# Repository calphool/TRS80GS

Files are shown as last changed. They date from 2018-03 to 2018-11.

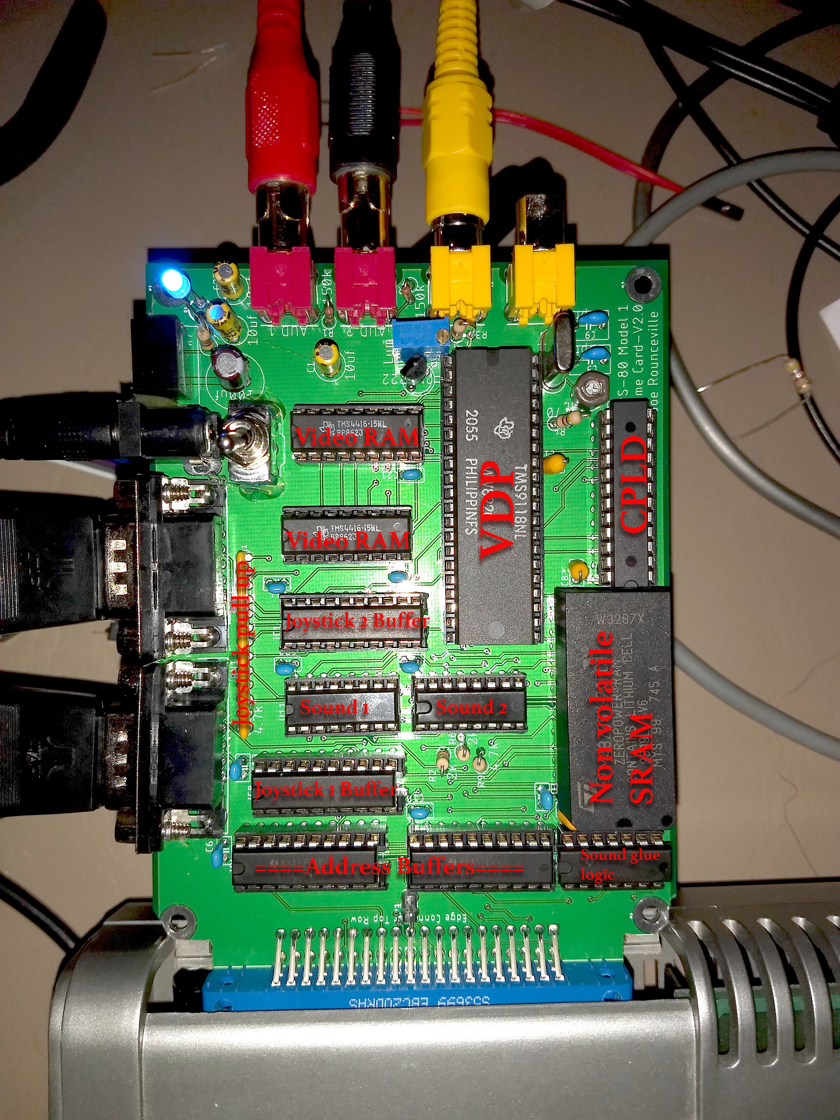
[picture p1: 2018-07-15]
img/TRS80GS_Version_3.jpg

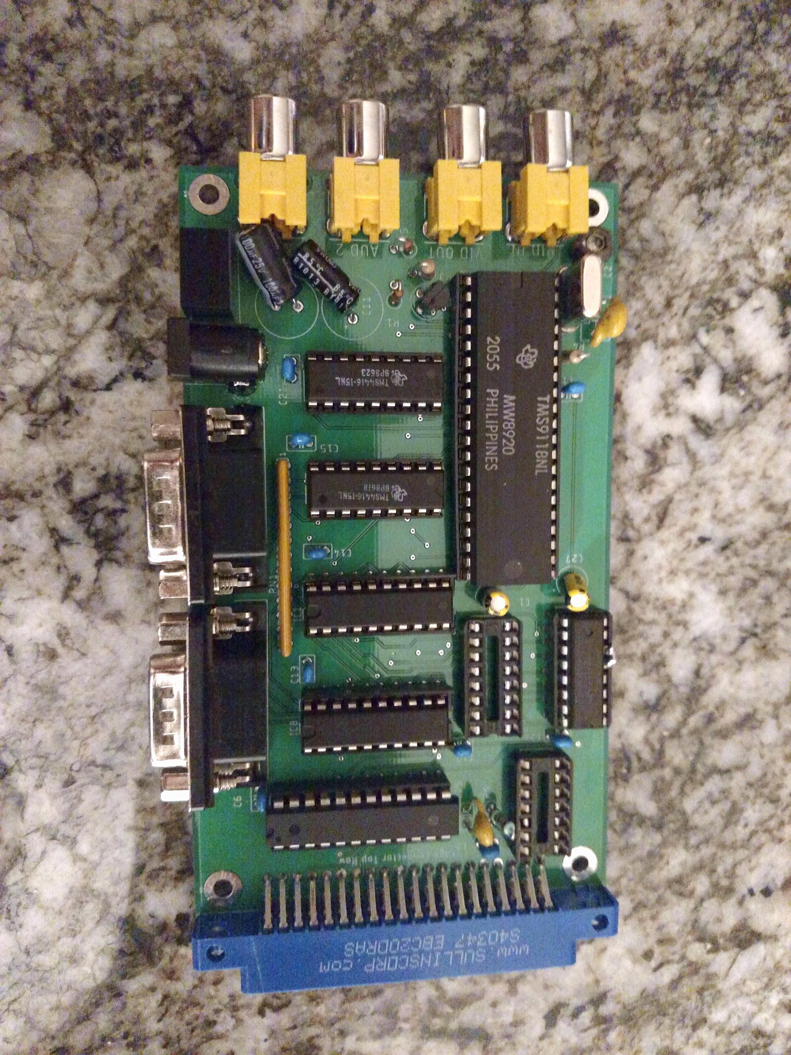
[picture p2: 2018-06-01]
img/TRS-80 Model 1 GraphicsSoundJoystick Card Prototype - Imgur.jpg

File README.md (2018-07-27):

# TRS80GS
Storage area for my TRS-80 Model 1 Graphics, Sound, Gaming, and Communication cartidge

Version 3 of PCB Version 4 of PCB

My friend's first computer was a 1977 TRS-80 Model 1.  I'm a few years younger than him, so my first computer was a TI-99/4A, 
followed soon after by an Atari 8-bit (800XL I believe).

For some reason my friend kept trying to assert that his *Trash-80* was in some way superior to all home computers of the era, 
and of course this couldn't stand.  I decided to see what all his fussing was about.  I learned some Z80 assembler, 
started hacking a TRS-80 emulator, and eventually got somewhat comfortable with Z80 assembler (I still prefer 6502 assembler).  I 
tried to do some graphics stuff, but *man*, TRS-80 Model 1's *barely* have the ability to do anything you'd call "graphics." 
I did a couple of snow-field type demos, but it looks more like slowly falling bricks on some low-gravity planet than snow.

The TRS-80 uses these goofy ["pseudographics" characters (2 by 3 grids)](https://www.classic-computers.org.nz/system-80/manuals_tm3_page33.jpg), 
and you have to do everything by selecting the right "character" in order to plot these huge blocky pixels.  Your resolution is effectively 128 x 48, and 
it's a pain to work with, because you're actually manipulating a 64 x 16 text grid.  I wrote some assembler code so that I could at least *address* 
the TRS-80 Model 1 screen *as if* it had 128 x 48 resolution, which I've included in this repo (see the snow.asm code, it's the FSETGR routine).

Eventually the day came that I thought "Ok, I'm going to try to write a game for this nasty old thing."  I *really* wanted 
graphics, sound, and a joystick, but alas that wasn't really in the cards for an unmodified TRS-80 Model 1.  So I began 
imagining what it would be like to augment a TRS-80 Model 1 so that it was *at least* as capable as *my* first computer, the 
TI.  I found a couple of dodgy designs for such devices from the era, but they were hand drawn, hard to read, and loaded with 
components that are no longer available.  So, I decided to design my own.

This repo is a gathering place for my work so far.  I've designed a cartridge that will plug into the TRS-80 Model 1 expansion 
port.  It is built around a TMS9118A video display processor (a close relative of the one used in the TI-99/4A and Colecovision).
It also includes two SN76489 sound chips (also from TI-99/4A, but *better* because we have two of them -- six voice harmony baby!)
I've also included a 74LS244 on the bus attached to an Atari 2600 joystick port (DB9), which in theory will give me the 
ability to poll for joystick condition.  That may end up being a bad design, since it's not using any interrupts, but I 
figured I'd start simple and if I need to implement interrupts I'll have to dig into how the TRS-80 deals with them.

**Be Aware**:  ~~I haven't built or tested my card yet (as of March 2018).  So it *probably* doesn't work as is.  We'll see as soon as 
I get finished testing the components individually with an Arduino as a kind of "hardware emulator".  I don't want to risk a 
"40 year old museum piece" while I figure out how to get the "glue" working properly.~~  I *have* now built a working prototype.  
You'll find the eaglecad and such in the rev2 folder (though you'd be better off using the rev4 version).  There's also some source code to test it once you get the board built.  

**Update**:  The photo is of the Rev4 version of this card.  It's fully working, and better than the rev2 and rev3.

Theory of Operation
===================

~~If you examine the *original* schematic for the board, you can see that it's got a bunch of decoding logic, and some SPDT dip switches.  The theory here 
is that I'm attaching the decoding logic to the lower half of [the expansion port's address bus](http://www.classiccmp.org/cpmarchives/trs80/mirrors/kjsl/www.kjsl.com/trs80/mod1intern.html) 
and using the OUT* and IN* pins to decide what we're doing.  In this way, the port address numbers will be adjustable.  
I'm hard wiring bit zero as a toggle bit though, so really you're adjusting the 7 most significant bits, and bit zero toggles 
between related devices or related pins on a device.~~

Strike all that... I pivoted on the design by rev2.  We got rid of silly things like glue logic chips (well, until rev4) and SPDT dip switches, and simply added 
a [CPLD](https://www.microchip.com/wwwproducts/en/ATF22V10C) that manages the address decoding and control signal generation.  The code for the CPLD is now in the repo.  So you 
"adjust" the addresses in code now, not with SPDT dip switches (what was I thinking?)  You program the CPLD with a Stager 4800 programmer, and a very particular version of 
its software (VSpeed 5.0).  Details are in the .PLD file in the repo.  I may eventually add another CPLD and get rid of the couple of glue chips I've got in the rev4 version.  Right now it doesn't 
seem worth it (get rid of two small chips and replace them with a big one?  Sounds like break even right now).

Rev3 includes some addtions.  First, it fixes the sound problem that the rev2 board had so we get both sound chips working (all 6 audio channels and 2 noise channels).  Second, it includes
a [32k SRAM](https://www.mouser.com/ProductDetail/511-M48Z35Y70PC1).  The original expansion system for the TRS-80 used DRAMs, but SRAM actually ends up being much better, especially when you use a non-volatile one like I have.  The Rev3 board 
also cleans up the joystick bodges that I had to do on the Rev2 board.  Rev3 works fully, and I've been building a Pacman game on it.

~~Rev4 is currently (July 2018) being built by our Chinese friends at allpcb.com, and it~~ is an upgraded version of Rev3 with one major improvement -- a [UART](https://en.wikipedia.org/wiki/16550_UART).  I 
~~*should* be~~ am able to connect a [FTDI cable](http://www.ftdichip.com/Products/Cables/USBTTLSerial.htm) via USB from my Mac to this UART and I should be able to transfer binary data back and forth.  
Initially I'll just use it to move my Pacman code back and forth, but in truth with a fully functional UART, I could build a kind of network interface and create something loosely equivalent to a LAN share, 
which would be sort of cool.  In fact, I *could* probably build a SLIP interface and do stuff like surf the web or use FTP from a 40 year old TRS-80 Model 1, but we'll save all that software work for a later date.

The only trouble with having a UART is that now I have *two* interrupts to deal with, so you won't be able to simultaneously use the VPD's interrupts *and* the UART's interrupts.  I've included
a jumper to allow you to switch which one you're working with.  I *suppose* I could add a latch behind an address so that you could tell which interrupt was being invoked, but honestly I 
can't imagine why we need to be both loading data *and* altering the screen at the same time, so Rev4 will use a jumper.  I think I'll start out without coding any interrupt stuff and see what I can get away with
using plain old polling.  It'll be slower, but simpler.  Once I get it working, then I'll look into trickier stuff like interrupt handling in z88dk.

Rev4 is now here and "working" though it took a little bit of hacking to get it up and running.  The original design for 
Rev4 included a separate crystal for the UART (1.8432mhz), but that proved problematic.  It caused the VDP crystal to 
act flaky due to interference.  So, I decided to try removing its crystal and all its support caps and resistors, and just 
drive the XTAL in for the UART from the CPUCLK output of the VDP.  It's the wrong speed (3.5mhz instead of 1.8432mhz), but 
luckily the UART has a divider value that you plug into a register during setup that allows it to use any chip slower than
16mhz.  I coded a couple of little test programs, one for the MAC (the "server") and one for the TRS-80 (the "client").  I
was able to transfer data back and forth, but I'm reaching out to folks on reddit to see if there's a better way to code 
it, since I have an arbitrary 8 millisecond wait on each byte transferred because I don't understand hardware flow control.

TMS9118A
--------
This little VDP chip has an interesting history.  It didn't disappear with the TI-99/4A.  It got used in the Colecovision, and
then its descendants got picked up and used in the MSX computer systems.  Later, it evolved into the graphics and sound chip
used in the Sega Master System and Sega Game Gear.  It has a bank of attached DRAM memory (16k), and you access this memory through
an 8 bit data bus and a few bus flags (MODE, CSR*, and CSW*).  It also has CAS and RAS signals to keep the DRAM running.  So, *technically*, in addition to getting decent graphics and 
sound with this card, we're also giving the TRS-80 Model 1 an additional 16k of RAM, though it's only accessible through a 
tiny keyhole of two IO ports, and much of it is used up by the VDP chip itself (depending on what mode you set it to).

~~At the time of this writing (March 2018), I've managed to bodge up a working TMS9118A on a breadboard, and drive it with an 
Arduino.  I've uploaded the Arduino code for that, and an incredibly frightening breadboard photo that looks like something out of 
the movie Aliens.  The code doesn't do anything too spectacular, but just changes the background color, which means that 
I've successfully managed to figure out how to drive the WRITE side of the chip (writing to what the VDP calls "control 
registers", which are how you set up almost everything in the VDP).  I've also included a small video showing it doing that.~~

We're way past that stage now.  The TMS9118 works like a dream, and I've been building a Pacman clone against it, using the z88dk C compiler.  So far I'm fitting inside my nice 32k RAM addition
just fine.  There's a lot of fluff in my code, and I'm pretty sure I could get it crammed down at least 25% if I worked at it.  Right now I've got an animated pacman that can move around inside
the maze, and I've got the intro music working.  Ghosts and dots coming soon....

SN76489
-------
~~I haven't done much with the sound chips yet, but hopefully they'll be a bit easier to manage than the VDP.  Bit 0 of the 
address bus will toggle between them.  Stereo baby!~~

Sound didn't work quite right in the rev2 board design.  There's a "Ready" line on the SN76489 that needed to be tied to the WAIT line on the TRS-80 interface.  Why?  Because the SN76489 doesn't
like receiving a second byte when it's still processing the first one.  I *could* write all my code to put a delay inbetween each byte send, but that's kind of lame and non-deterministic.  The
WAIT line was originally conceived so that the TRS-80 could interface to "slow" peripherals, and although the sound chip isn't *super* slow, it seemed the way to go was to tie that READY line 
to it.  Unfortunately on the rev2 board that meant that I couldn't use *both* sound chips, because I didn't have a free OR gate anywhere to run the two Ready lines through.  So, I pulled one of them
and just wired the other one up on the rev2 board.  It worked as expected.  This has all been cleaned up in the rev3 and rev4 boards.

74LS244
-------
This is managing the joystick switches.  It takes 5 switches to handle up, down, left, right, and trigger.  ~~I don't have any
kind of debounce circuit in there, so I'm guessing that'll be a problem.  We'll see when we get there.~~

Joystick circuits worked more or less flawlessly, though I had stuff wired backward on the PCB for rev2.  I had to bodge some jumper wires to get them working because of that, but that's all cleaned 
up in Rev3 and Rev4.  I originally was toying with the idea of building some kind of one-way parallel interface that used the joystick ports, but the more I thought about it the less I liked it and
decided to add the UART instead.

ExtVid
------
I don't really know if I'll do this, but it's sort of an intriguing idea.  Apparently the TMS9118A has a "video input" pin, 
believe it or not.  In principle at least, I could feed the video out of the TRS-80 to the video-input of the TMS9118A, and it
will *combine* the video together, with the TRS-80's video feed at the bottom of the stack of planes that the TMS9118A creates (which, 
by the way is how it manages sprites -- 32 of them as separate planes stacked on top of each other).  If I do this, and it 
works, it could create some interesting possibilities.  You'd still have the "feel" of a TRS-80 Model 1 with its nasty, clunky
pseudographics, but then you could overlay color and sprites over the top of it.  I guess we'll see when we get there.  The 
current (March 2018) schematics don't implement this idea.

(July 2018) I haven't done anything with ExtVid yet.  I've come to realize that it's unlikely to just work out of the box, because the 
RESET line on the TMS9118A does double duty as some kind of video sync signal.  So I'd probably have to come up with a sync separator 
circuit for the ExtVid line, then amplify that signal up to whatever ungodly voltage causes the RESET to act like a SYNC signal.  I probably should just
hook up a video signal to see how bad it tears as it moves down the screen -- maybe it's still usable without all that extra circuitry -- just haven't 
tried it yet.

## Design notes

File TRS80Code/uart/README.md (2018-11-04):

Getting UART code working for TRS80GS
-------------------------------------

Make sure you've followed this power-up sequence:

    A) Turn on TRS80GS card
    B) Power on TRS-80
    C) Plug in FTDI cable to Mac USB
    D) Start uart_server executable

Also, don't use the Reset button on the TRS-80.  It creates chaos.  Use the power button.

The UART file upload/download system works in two parts.  First there is a TRS-80 binary module
that loads into the SRAM of the TRS80GS card.  Steps 1 - 6 must be completed any time you 
change the uart.c module.

The second part is the Mac server component.  It runs on your Mac (although it *might* work on a)
PC that has GCC, I've not tried it there, and I wouldn't be surprised if the serial code didn't 
work the same way).  It basically listens for commands from the UART chip and responds appropriately.

Step 1.  Compile uart.c using cmp.sh, which produces a .cmd and a .wav file 

	:~/z88dk/cmp.sh uart 55000

	Note: the 55000 is the address you want the uart client code to load to.  Make sure that the 
	.cmd file fits inside the space you specify.  The address space for the Z80 is 
	0x0000 to 0xffff.  If your .cmd file is 7k, then you would use 0xffff-(7*1024), or
	58368 (0xE400).  You can use a lower value that that (and probably should), but that would be 
	the maximum.  Depending on the details of how the compiler optimizes, that may not be low 
	enough.  I generally subtract an addtional 3000 so that I don't have to worry about it.

Step 2.  Load the uart.wav file into Audacity and amplify it 8 db.  (You must allow clipping.)

Step 3.  Turn on your TRS-80 Model 1.  When you see the MEM SIZE? prompt, type 18000
         Then connect your TRS80 cassette line to your Mac or PC.

Step 4.  On the TRS-80 type:

         SYSTEM

         *? A

Step 5.  Press PLAY on Audacity

     Note: if you are using an official TRS-80 cassette cable, you'll be using the black 
     plug into your Mac or PC.  Also, note that as the data loads, you should see a couple of 
     asterisks in the top right side of the screen, with the right one flashing off and on
     as the data loads.

Step 6.  Once the data is loaded type:

         *? /55000

     Note that the number you type should match what you specified in step 1.  The UART 
     program should appear on screen and ask you for a command.  You can type ? to see 
     the list of commands it supports.

Step 7.  Compile the Mac server component.
     :~/TRS80GS/OSXCode$ gcc uart_server.c

Step 8.  Execute the Mac server code.
     :~/TRS80GS/OSXCode$ ./uart_server

     Note: you should see something like:

         Starting...
         Getting devices...
         Searching for non-bluetooth tty devices...
             ...ignoring bluetooth device: tty.Bluetooth-Incoming-Port ...

         Found 1 valid serial device(s).
         Defaulting to serial device: tty.usbserial-AI055XFC
         Opening...
         Waiting for command.

Step 9.  On the TRS-80 command prompt, type:

         >LS

     Note: you should see a list of files that are in the same directory as the uart_server. 
     If you have no .CMD files, you need to find some and put them in that directory and try again.

Step 10.  To load a .CMD file, at the TRS-80 type:

         >GET LASERDEF.CMD

     Note:  You will see a progress bar as the .CMD file is loaded into memory and the console on
            the Mac uart_server app will show a percentage loaded, like this:

		     Get Command requested...
		        GET LASERDEF.CMD
		        Reading Object block, addr 0x8000, length = 128 (0 percent complete)
				Reading Object block, addr 0x8080, length = 128 (1 percent complete)
				Reading Object block, addr 0x8100, length = 128 (2 percent complete)
				Reading Object block, addr 0x8180, length = 128 (3 percent complete)
				Reading Object block, addr 0x8200, length = 128 (5 percent complete)
				Reading Object block, addr 0x8280, length = 128 (6 percent complete)
				Reading Object block, addr 0x8300, length = 128 (7 percent complete)
				Reading Object block, addr 0x8380, length = 128 (9 percent complete)
				Reading Object block, addr 0x8400, length = 128 (10 percent complete)
				Reading Object block, addr 0x8480, length = 128 (11 percent complete)
				Reading Object block, addr 0x8500, length = 128 (13 percent complete)
				Reading Object block, addr 0x8580, length = 128 (14 percent complete)

    After it finishes loading, you should see:

        PROGRAM ENTRY POINT: xxxxxx
        ENTER 'G' TO RUN AT ENTRY POINT, or 'C' TO CANCEL

    Normally you want to type G at this point.  If you know what you're doing, you could type C to 
    get back to the command prompt to load something else into memory.

Step 11.  Once you're done with whatever you loaded, you can restart your TRS-80 and the code for the 
          uart client should still be memory resident (as long as whatever you loaded didn't corrupt it).

          So, just start your TRS-80 again, use 18000 for your memory size, type SYSTEM and then:

          *? /55000

          to launch the UART client to load something different.  If the UART client gets corrupted, 
          you will need to run steps 4 - 6 again.  However, it is rare for a .CMD to use memory outside 
          of where it was loaded, so this should rarely happen.

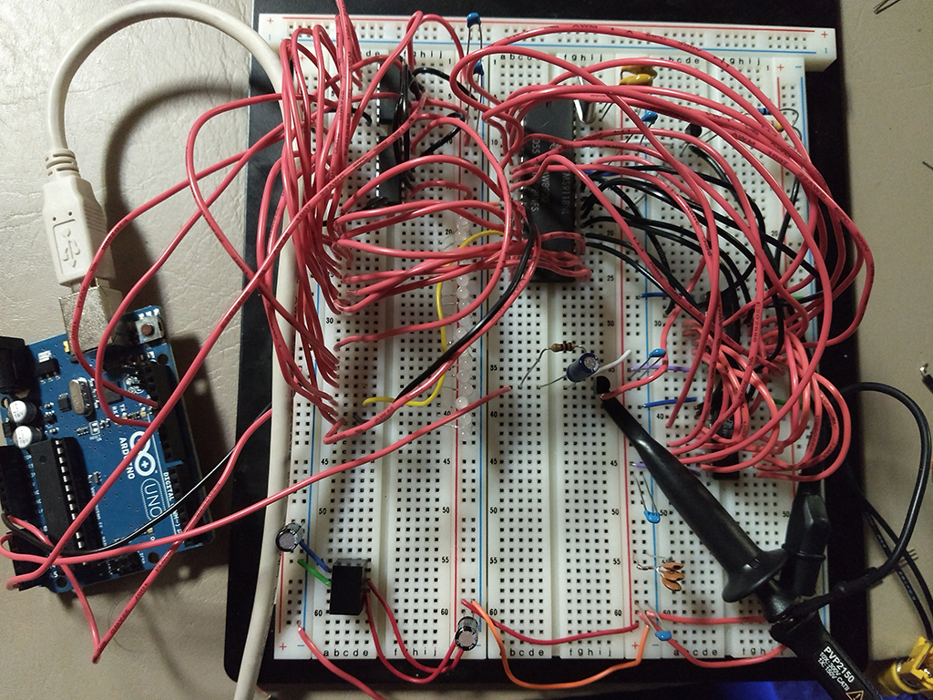
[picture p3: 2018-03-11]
arduino_prototyping/Breadboard_Monstrosity.jpg

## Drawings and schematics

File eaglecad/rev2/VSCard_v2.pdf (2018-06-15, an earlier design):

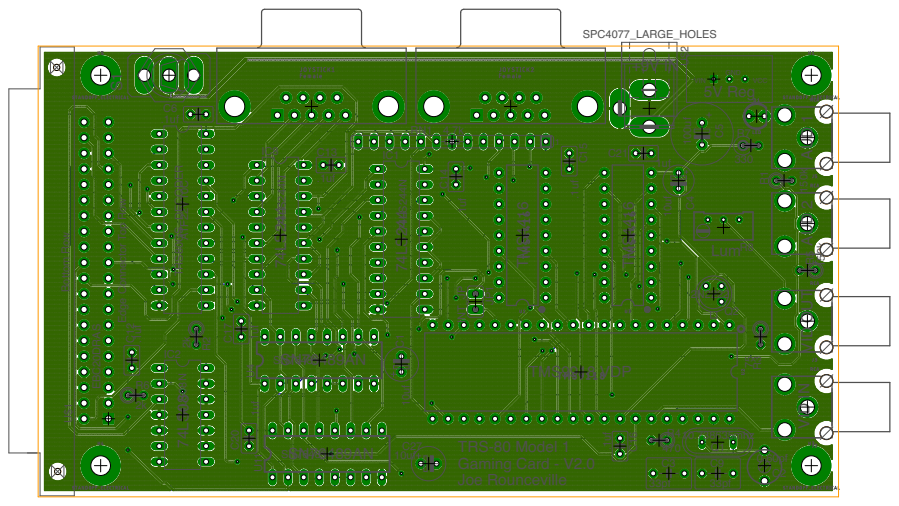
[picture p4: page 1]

Edge Connector Top Row

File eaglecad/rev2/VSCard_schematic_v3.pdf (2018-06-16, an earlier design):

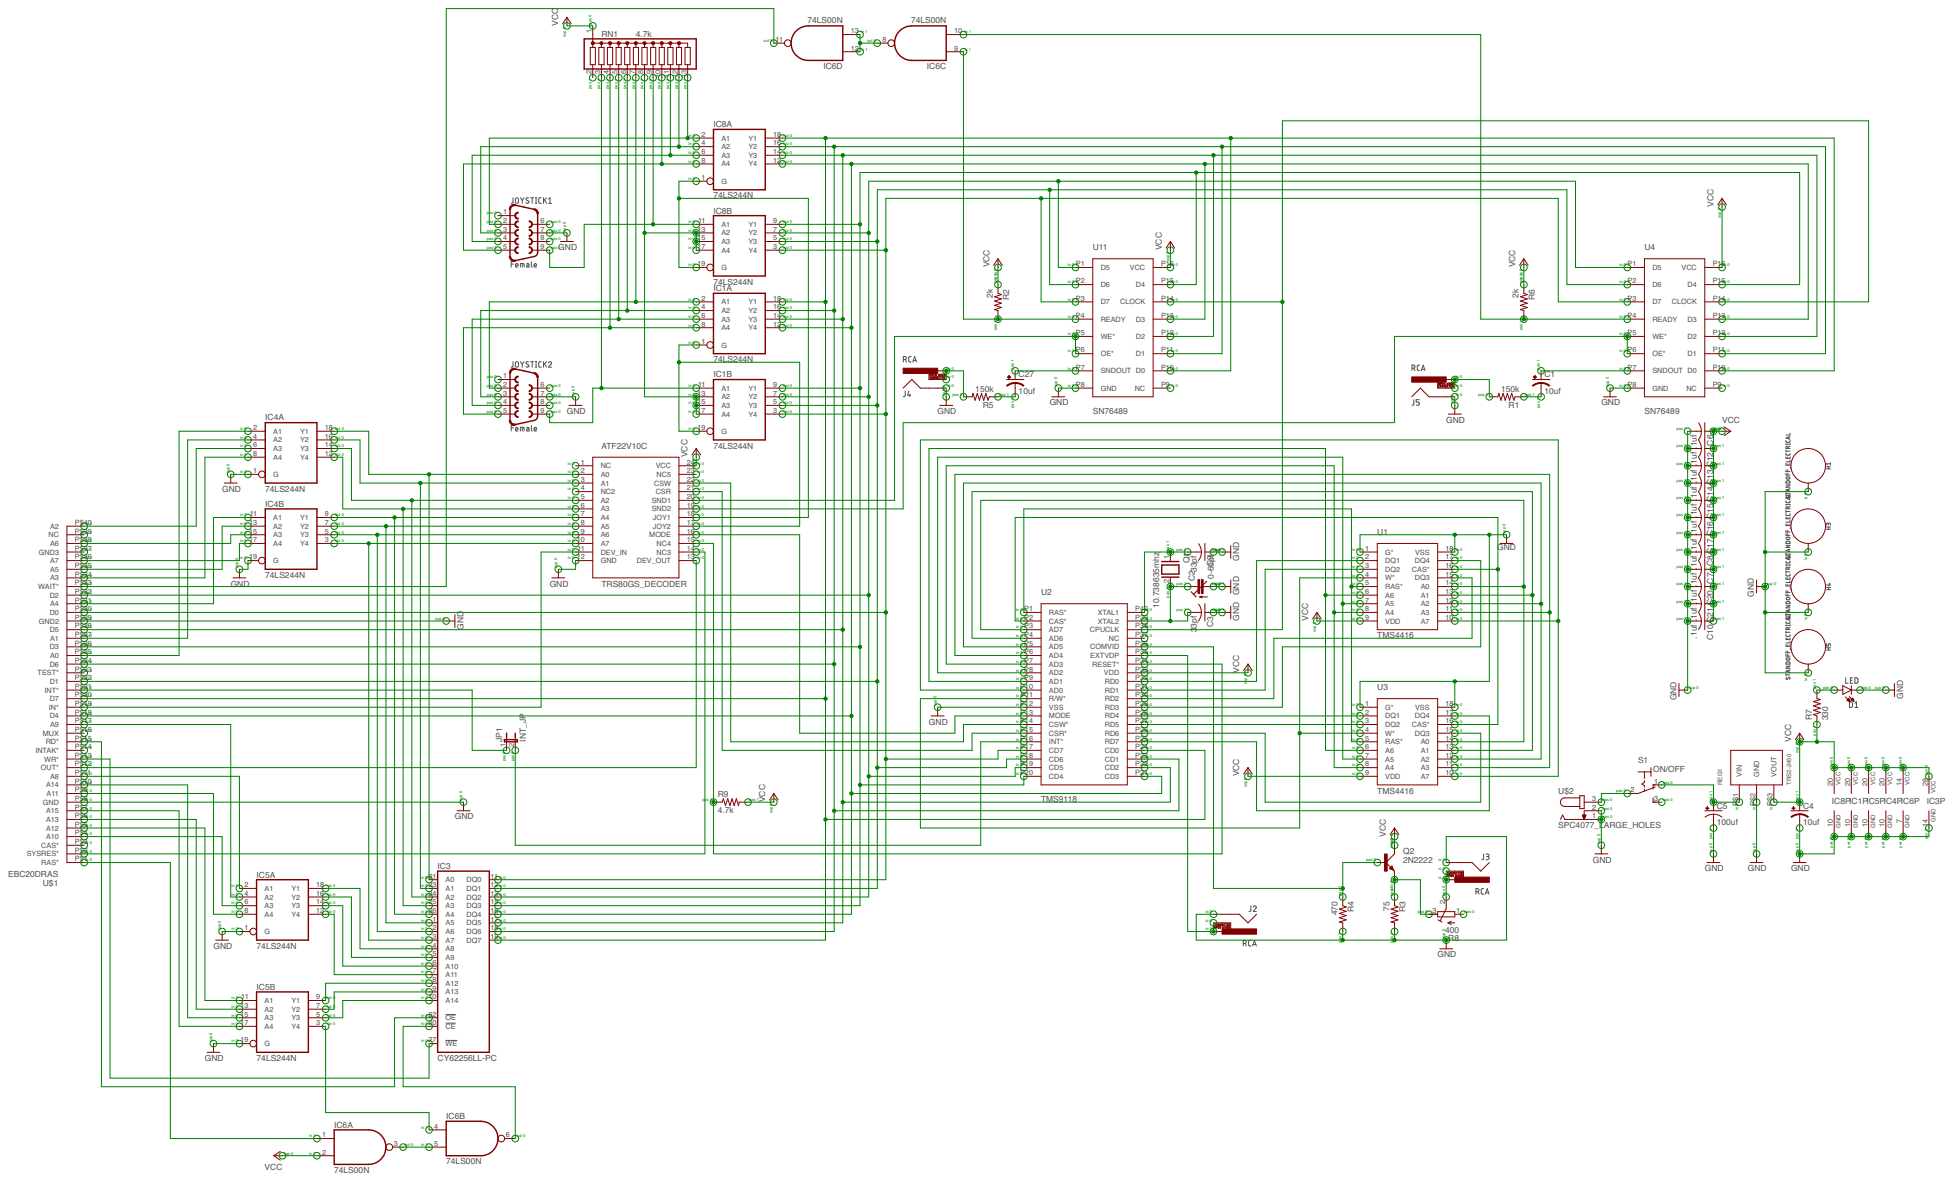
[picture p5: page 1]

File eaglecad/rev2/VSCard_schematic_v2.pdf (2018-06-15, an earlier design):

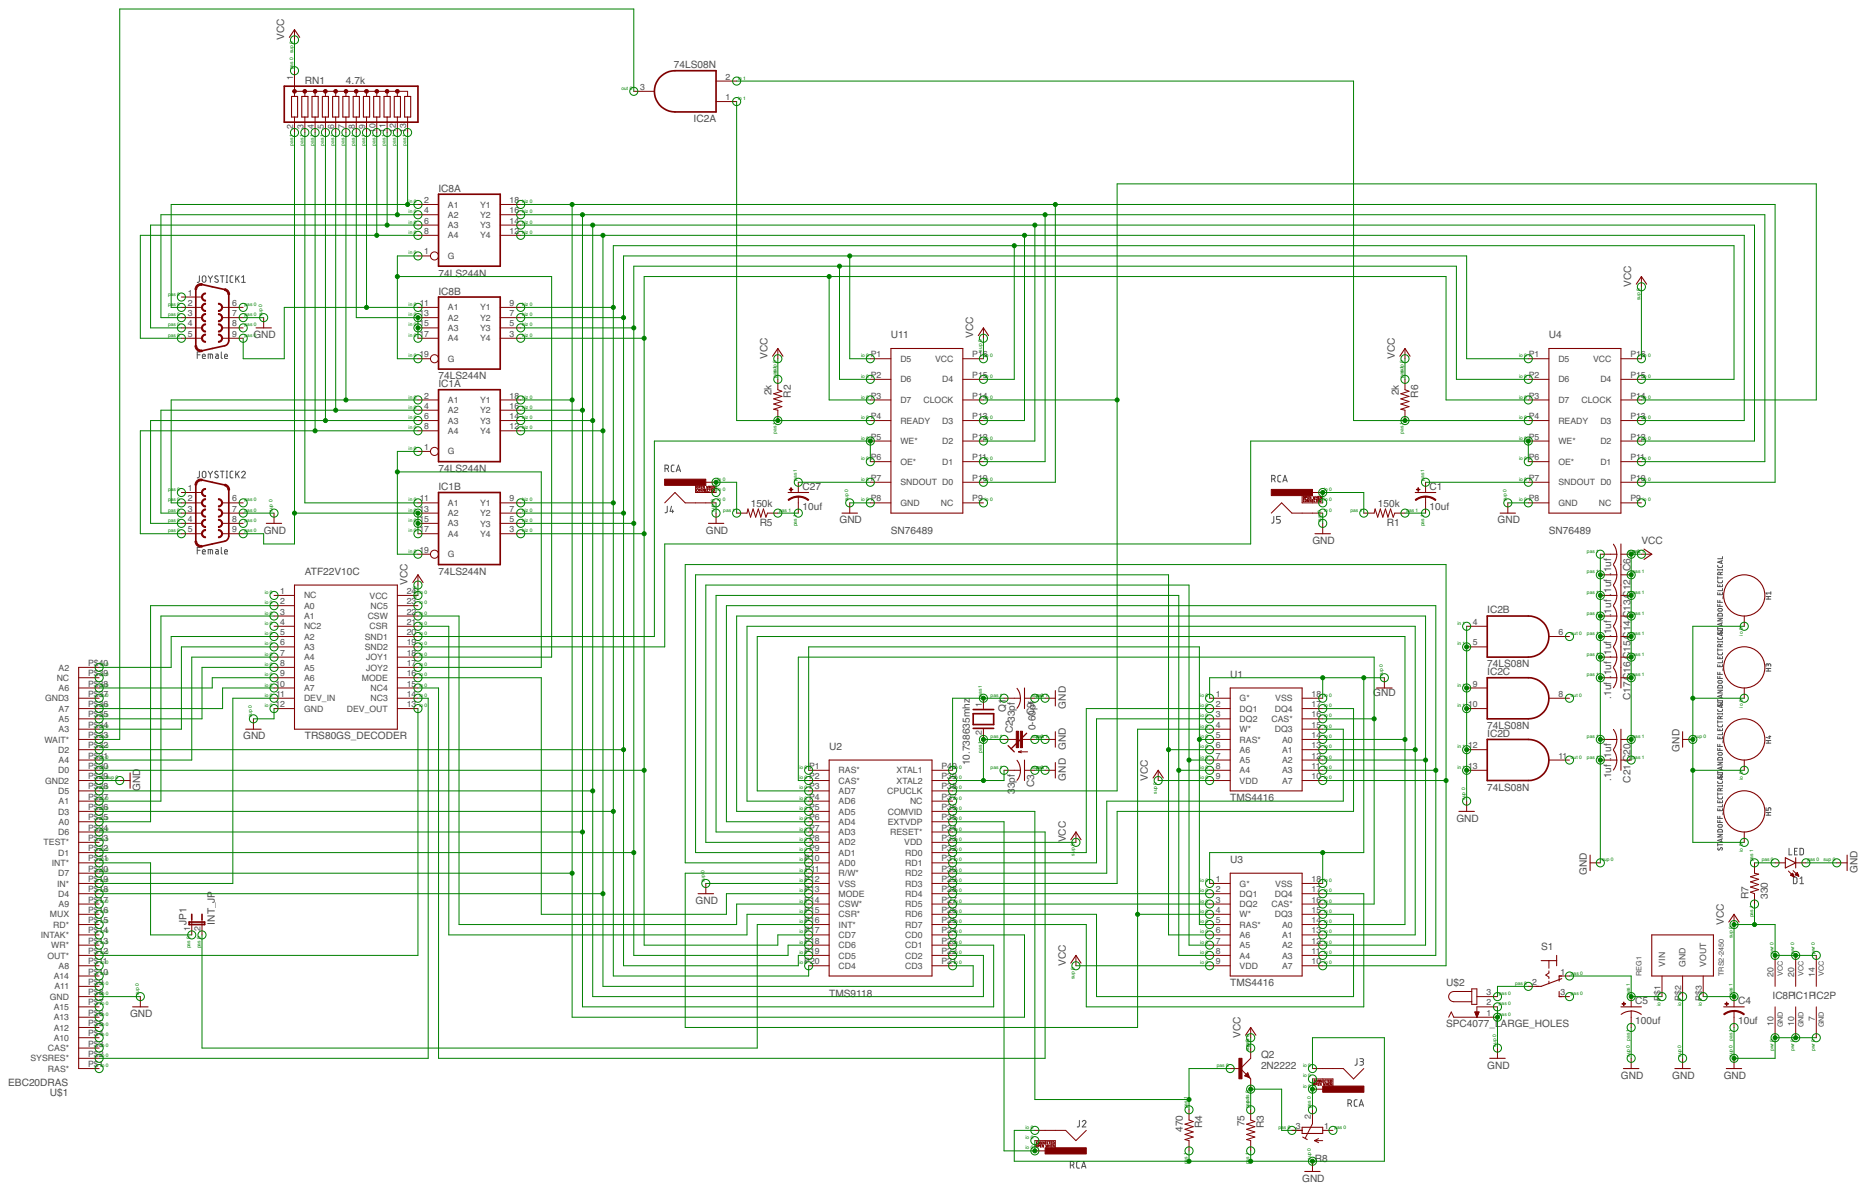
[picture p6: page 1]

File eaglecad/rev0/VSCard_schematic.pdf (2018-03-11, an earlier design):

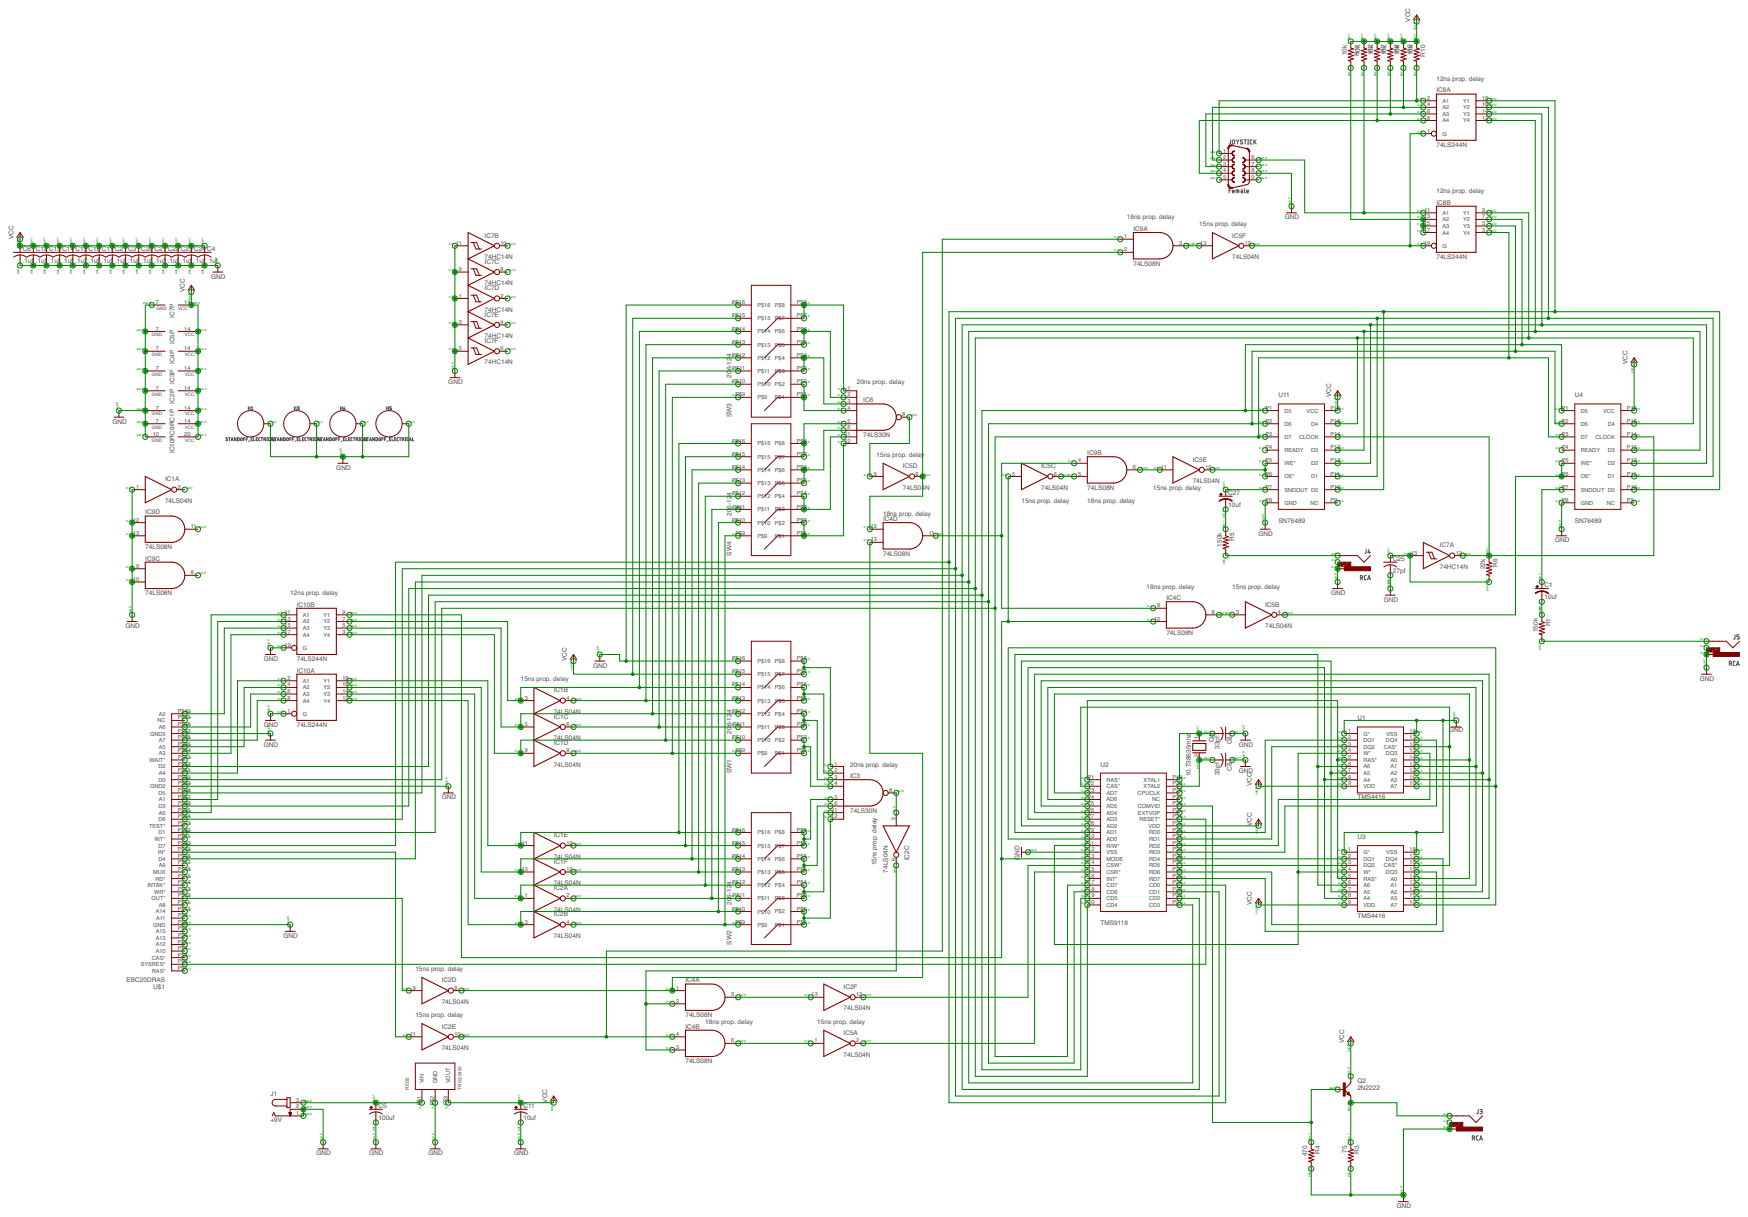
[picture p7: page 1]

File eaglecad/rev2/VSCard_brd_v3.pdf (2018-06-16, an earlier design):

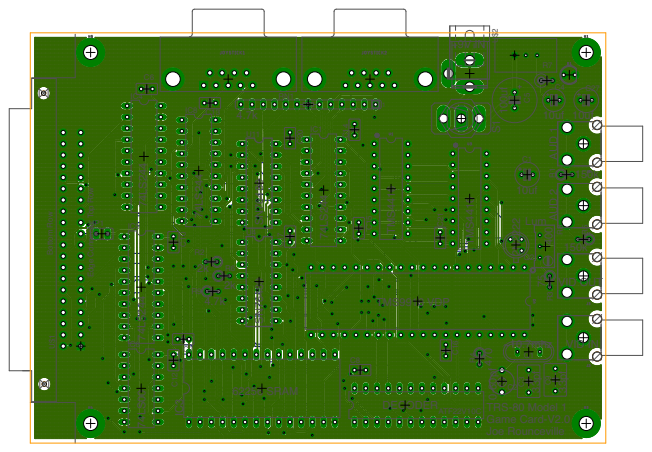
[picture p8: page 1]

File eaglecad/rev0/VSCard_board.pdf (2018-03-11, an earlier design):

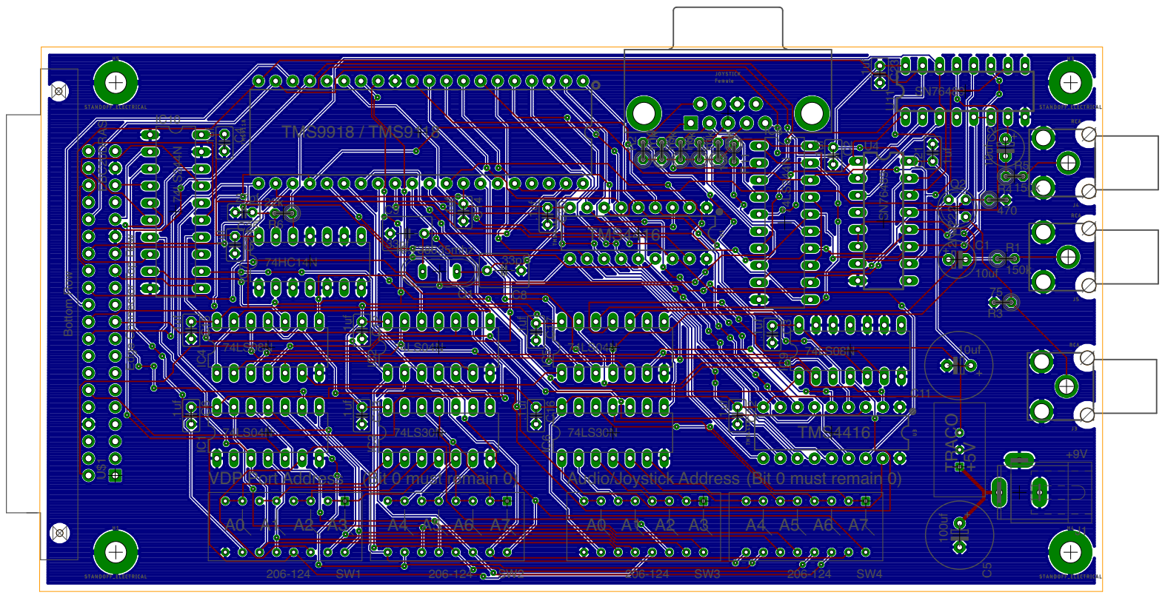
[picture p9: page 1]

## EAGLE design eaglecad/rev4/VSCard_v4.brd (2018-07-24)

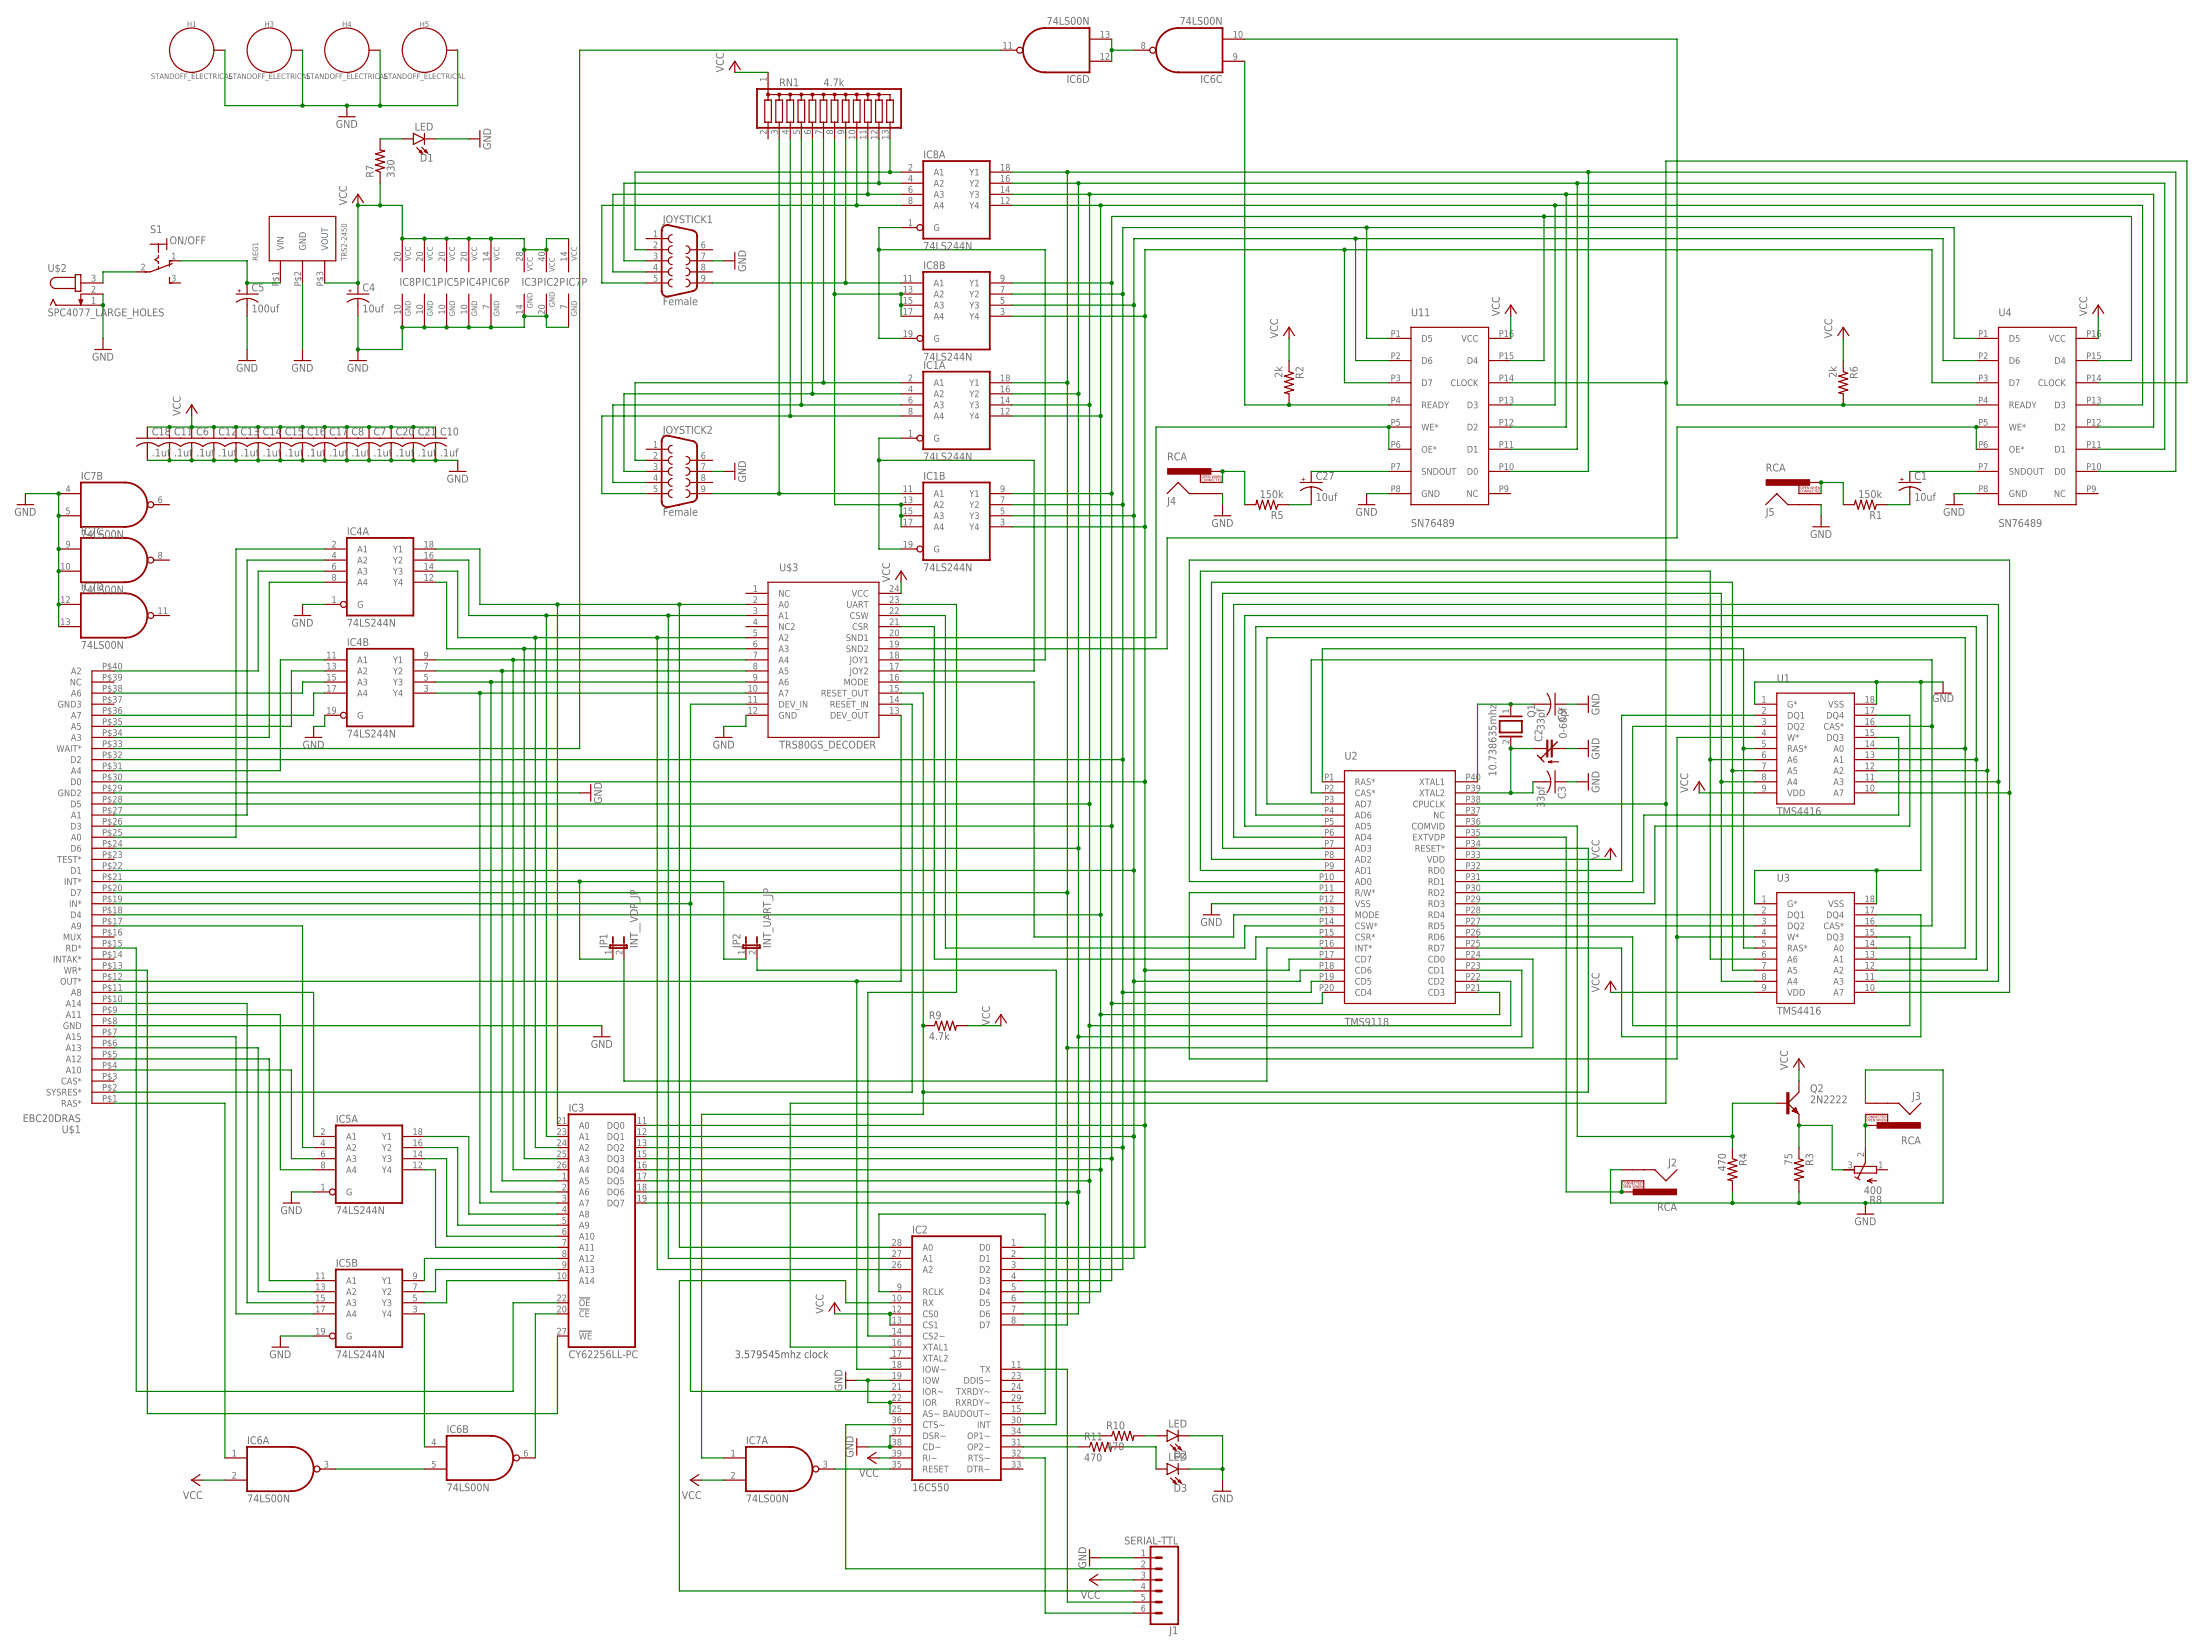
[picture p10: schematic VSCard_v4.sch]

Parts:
C1, C27: 10uf; E2,5-6
C2: 0-60pf; CTRIM3050.504
C3, C9: 33pf; C050-050X075
C4: 10uf; E2,5-5
C5: 100uf; E3,5-10
C6, C7, C8, C10, C11, C12, C13, C14, C15, C16, C17, C18, C20, C21: .1uf; C025-025X050
D1, D2, D3: LED; LED_3MM
H1, H3, H4, H5: STANDOFF_ELECTRICAL; STANDOFF-ELECTRICAL
IC1, IC4, IC5, IC8: 74LS244N; DIL20
IC2: 16C550; DIL40
IC3: CY62256LL-PC; DIL28-6
IC6, IC7: 74LS00N; DIL14
J1: SERIAL-TTL; 1X06_NO_SILK
J2, J3, J4, J5: RCA
JOYSTICK1, JOYSTICK2: Female; DB9
JP1: INT__VDP_JP; JP1
JP2: INT_UART_JP; JP1
Q1: 10.738635mhz; QS
Q2: 2N2222; TO18A
R1, R5: 150k; 0207/2V
R2, R6: 2k; 0207/2V
R3: 75; 0207/2V
R4, R10, R11: 470; 0207/2V
R7: 330; 0309V
R8: 400; RTRIM64W
R9: 4.7k; 0207/2V
REG1: TRS2-2450; TRACON_REG
RN1: 4.7k; SIL13
S1: ON/OFF; 320-916
U1, U3: TMS4416; DIP18
U2: TMS9118; DIP40_MCU
U4, U11: SN76489; DIP16
U$1: EBC20DRAS
U$2: SPC4077_LARGE_HOLES; SPC4077
U$3: TRS80GS_DECODER; DIP24SKI

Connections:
A0_BUFFERED: IC2.28 (A0), IC3.21 (A0), IC4.18 (Y1), U$3.2 (A0)
A0_RAW: IC4.2 (A1), U$1.P$25 (A0)
A1_BUFFERED: IC2.27 (A1), IC3.23 (A1), IC4.16 (Y2), U$3.3 (A1)
A1_RAW: IC4.4 (A2), U$1.P$27 (A1)
A2_BUFFERED: IC2.26 (A2), IC3.24 (A2), IC4.14 (Y3), U$3.5 (A2)
A2_RAW: IC4.6 (A3), U$1.P$40 (A2)
A3_BUFFERED: IC3.25 (A3), IC4.12 (Y4), U$3.6 (A3)
A3_RAW: IC4.8 (A4), U$1.P$34 (A3)
A4_BUFFERED: IC3.26 (A4), IC4.9 (Y1), U$3.7 (A4)
A4_RAW: IC4.11 (A1), U$1.P$31 (A4)
A5_BUFFERED: IC3.1 (A5), IC4.7 (Y2), U$3.8 (A5)
A5_RAW: IC4.13 (A2), U$1.P$35 (A5)
A6_BUFFERED: IC3.2 (A6), IC4.5 (Y3), U$3.9 (A6)
A6_RAW: IC4.15 (A3), U$1.P$38 (A6)
A7_BUFFERED: IC3.3 (A7), IC4.3 (Y4), U$3.10 (A7)
A7_RAW: IC4.17 (A4), U$1.P$36 (A7)
A8_BUFFERED: IC3.4 (A8), IC5.18 (Y1)
A8_RAW: IC5.2 (A1), U$1.P$11 (A8)
A9_BUFFERED: IC3.5 (A9), IC5.16 (Y2)
A9_RAW: IC5.4 (A2), U$1.P$17 (A9)
A10_BUFFERED: IC3.6 (A10), IC5.14 (Y3)
A10_RAW: IC5.6 (A3), U$1.P$4 (A10)
A11_BUFFERED: IC3.7 (A11), IC5.12 (Y4)
A11_RAW: IC5.8 (A4), U$1.P$9 (A11)
A12_BUFFERED: IC3.8 (A12), IC5.9 (Y1)
A12_RAW: IC5.11 (A1), U$1.P$5 (A12)
A13_BUFFERED: IC3.9 (A13), IC5.7 (Y2)
A13_RAW: IC5.13 (A2), U$1.P$6 (A13)
A14_BUFFERED: IC3.10 (A14), IC5.5 (Y3)
A14_RAW: IC5.15 (A3), U$1.P$10 (A14)
A15_BUFFERED: IC5.3 (Y4), IC6.4 (I0)
A15_RAW: IC5.17 (A4), U$1.P$7 (A15)
COMVID: Q2.B, R4.1, U2.P36 (COMVID)
COMVID-OUT: Q2.E, R3.1, R8.3 (E)
CTS*: IC2.36 (CTS~), J1.2
D0: IC1.3 (Y4), IC2.1 (D0), IC3.11 (DQ0), IC8.3 (Y4), U2.P17 (CD7), U4.P3 (D7), U11.P3 (D7), U$1.P$30 (D0)
D1: IC1.5 (Y3), IC2.2 (D1), IC3.12 (DQ1), IC8.5 (Y3), U2.P18 (CD6), U4.P2 (D6), U11.P2 (D6), U$1.P$22 (D1)
D2: IC1.7 (Y2), IC2.3 (D2), IC3.13 (DQ2), IC8.7 (Y2), U2.P19 (CD5), U4.P1 (D5), U11.P1 (D5), U$1.P$32 (D2)
D3: IC1.9 (Y1), IC2.4 (D3), IC3.15 (DQ3), IC8.9 (Y1), U2.P20 (CD4), U4.P15 (D4), U11.P15 (D4), U$1.P$26 (D3)
D4: IC1.12 (Y4), IC2.5 (D4), IC3.16 (DQ4), IC8.12 (Y4), U2.P21 (CD3), U4.P13 (D3), U11.P13 (D3), U$1.P$18 (D4)
D5: IC1.14 (Y3), IC2.6 (D5), IC3.17 (DQ5), IC8.14 (Y3), U2.P22 (CD2), U4.P12 (D2), U11.P12 (D2), U$1.P$28 (D5)
D6: IC1.16 (Y2), IC2.7 (D6), IC3.18 (DQ6), IC8.16 (Y2), U2.P23 (CD1), U4.P11 (D1), U11.P11 (D1), U$1.P$24 (D6)
D7: IC1.18 (Y1), IC2.8 (D7), IC3.19 (DQ7), IC8.18 (Y1), U2.P24 (CD0), U4.P10 (D0), U11.P10 (D0), U$1.P$20 (D7)
DOWN: IC8.4 (A2), JOYSTICK1.3, RN1.12
DOWN1: IC1.4 (A2), JOYSTICK2.3, RN1.6
GND: C2.2 (A), C3.1, C4.-, C5.-, C6.2, C7.2, C8.2, C9.1, C10.2, C11.2, C12.2, C13.2, C14.2, C15.2, C16.2, C17.2, C18.2, C20.2, C21.2, D1.K (C), D2.K (C), D3.K (C), H1.P1, H3.P1, H4.P1, H5.P1, IC1.10 (GND), IC2.19 (IOW), IC2.20 (GND), IC2.22 (IOR), IC2.25 (AS~), IC2.37 (DSR~), IC2.38 (CD~), IC3.14 (GND), IC4.1 (G), IC4.10 (GND), IC4.19 (G), IC5.1 (G), IC5.10 (GND), IC5.19 (G), IC6.7 (GND), IC7.4 (I0), IC7.5 (I1), IC7.7 (GND), IC7.9 (I0), IC7.10 (I1), IC7.12 (I0), IC7.13 (I1), IC8.10 (GND), J1.1, J2.SHELL, J3.SHELL, J4.SHELL, J5.SHELL, JOYSTICK1.7, JOYSTICK2.7, R3.2, R4.2, REG1.P$2 (GND), U1.1 (G*), U1.18 (VSS), U2.P12 (VSS), U3.1 (G*), U3.18 (VSS), U4.P8 (GND), U11.P8 (GND), U$1.P$8 (GND), U$1.P$29 (GND2), U$2.1, U$2.2, U$3.12 (GND)
IN*: IC2.21 (IOR~), U$1.P$19 (IN*), U$3.11 (DEV_IN)
INT*: JP1.1, JP2.1, U$1.P$21 (INT*)
JOY1_IN_ENABLE_N: IC8.1 (G), IC8.19 (G), U$3.18 (JOY1)
JOY1_IN_ENABLE_N1: IC1.1 (G), IC1.19 (G), U$3.17 (JOY2)
LEFT: IC8.6 (A3), JOYSTICK1.4, RN1.11
LEFT1: IC1.6 (A3), JOYSTICK2.4, RN1.5
unnamed: J4.PIN, J4.SWITCH, R5.2
unnamed: S1.2, U$2.3
unnamed: JP1.2, U2.P16 (INT*)
unnamed: J3.PIN, J3.SWITCH, R8.2 (S)
unnamed: IC2.30 (INT), JP2.2
unnamed: IC2.14 (CS2~), U$3.23 (UART)
unnamed: IC2.35 (RESET), IC7.3 (O)
unnamed: IC2.34 (OP1~), R10.1
unnamed: IC2.31 (OP2~), R11.1
unnamed: D2.A, R10.2
unnamed: D3.A, R11.2
unnamed: U2.P14 (CSW*), U$3.22 (CSW)
unnamed: U2.P15 (CSR*), U$3.21 (CSR)
unnamed: C2.1 (E), C3.2, Q1.2, U2.P39 (XTAL2)
unnamed: J2.PIN, J2.SWITCH, U2.P35 (EXTVDP)
unnamed: U1.5 (RAS*), U2.P1 (RAS*), U3.5 (RAS*)
unnamed: D1.A, R7.2
unnamed: U1.16 (CAS*), U2.P2 (CAS*), U3.16 (CAS*)
unnamed: IC2.9 (RCLK), IC2.15 (BAUDOUT~)
unnamed: J5.PIN, J5.SWITCH, R1.2
unnamed: IC6.1 (I0), U$1.P$1 (RAS*)
unnamed: IC6.3 (O), IC6.5 (I1)
unnamed: IC3.20 (!CE), IC6.6 (O)
unnamed: IC6.8 (O), IC6.12 (I0), IC6.13 (I1)
unnamed: C27.-, R5.1
unnamed: C1.-, R1.1
unnamed: IC1.13 (A2), IC1.15 (A3), IC1.17 (A4), IC8.13 (A2), IC8.15 (A3), IC8.17 (A4), RN1.8
OUT*: IC2.18 (IOW~), U$1.P$12 (OUT*), U$3.13 (DEV_OUT)
RD_: IC3.22 (!OE), U$1.P$15 (RD*)
RIGHT: IC8.8 (A4), JOYSTICK1.5, RN1.10
RIGHT1: IC1.8 (A4), JOYSTICK2.5, RN1.4
RTS*: IC2.32 (RTS~), J1.6
SIN: IC2.10 (RX), J1.4
SN76489-CLOCK: IC2.16 (XTAL1), U2.P38 (CPUCLK), U4.P14 (CLOCK), U11.P14 (CLOCK)
SND1_ENABLE_N: U11.P5 (WE*), U11.P6 (OE*), U$3.20 (SND1)
SND1_READY: IC6.9 (I0), R2.2, U11.P4 (READY)
SND2_ENABLE_N: U4.P5 (WE*), U4.P6 (OE*), U$3.19 (SND2)
SND2_READY: IC6.10 (I1), R6.2, U4.P4 (READY)
SNDOUT1: C27.+, U11.P7 (SNDOUT)
SNDOUT2: C1.+, U4.P7 (SNDOUT)
SOUT: IC2.11 (TX), J1.5
SYSRESET*: U$1.P$2 (SYSRES*), U$3.14 (RESET_IN)
TMS9118_RW(*)_TMS4416_W(*): U1.4 (W*), U2.P11 (R/W*), U3.4 (W*)
TMS9918_AD0-TMS4416_A7: U1.10 (A7), U2.P10 (AD0), U3.10 (A7)
TMS9918_AD1-TMS4416_A6: U1.6 (A6), U2.P9 (AD1), U3.6 (A6)
TMS9918_AD2-TMS4416_A5: U1.7 (A5), U2.P8 (AD2), U3.7 (A5)
TMS9918_AD3-TMS4416_A4: U1.8 (A4), U2.P7 (AD3), U3.8 (A4)
TMS9918_AD4-TMS4416_A3: U1.11 (A3), U2.P6 (AD4), U3.11 (A3)
TMS9918_AD5-TMS4416_A2: U1.12 (A2), U2.P5 (AD5), U3.12 (A2)
TMS9918_AD6-TMS4416_A1: U1.13 (A1), U2.P4 (AD6), U3.13 (A1)
TMS9918_AD7-TMS4416_A0: U1.14 (A0), U2.P3 (AD7), U3.14 (A0)
TRIGGER: IC8.11 (A1), JOYSTICK1.9, RN1.9
TRIGGER1: IC1.11 (A1), JOYSTICK2.9, RN1.3
UP: IC8.2 (A1), JOYSTICK1.2, RN1.13
UP1: IC1.2 (A1), JOYSTICK2.2, RN1.7
VCC: C4.+, C6.1, C7.1, C8.1, C10.1, C11.1, C12.1, C13.1, C14.1, C15.1, C16.1, C17.1, C18.1, C20.1, C21.1, IC1.20 (VCC), IC2.12 (CS0), IC2.13 (CS1), IC2.39 (RI~), IC2.40 (VCC), IC3.28 (VCC), IC4.20 (VCC), IC5.20 (VCC), IC6.2 (I1), IC6.14 (VCC), IC7.2 (I1), IC7.14 (VCC), IC8.20 (VCC), J1.3, Q2.C, R2.1, R6.1, R7.1, R9.2, REG1.P$3 (VOUT), RN1.1, U1.9 (VDD), U2.P33 (VDD), U3.9 (VDD), U4.P16 (VCC), U11.P16 (VCC), U$3.24 (VCC)
VDP-RD0: U1.2 (DQ1), U2.P32 (RD0)
VDP-RD1: U1.3 (DQ2), U2.P31 (RD1)
VDP-RD2: U1.15 (DQ3), U2.P30 (RD2)
VDP-RD3: U1.17 (DQ4), U2.P29 (RD3)
VDP-RD4: U2.P28 (RD4), U3.2 (DQ1)
VDP-RD5: U2.P27 (RD5), U3.3 (DQ2)
VDP-RD6: U2.P26 (RD6), U3.15 (DQ3)
VDP-RD7: U2.P25 (RD7), U3.17 (DQ4)
VDP_MODE: U2.P13 (MODE), U$3.16 (MODE)
VID_RESET*: IC7.1 (I0), R9.1, U2.P34 (RESET*), U$3.15 (RESET_OUT)
VOLTAGE-IN: C5.+, REG1.P$1 (VIN), S1.1 (O)
WAIT*: IC6.11 (O), U$1.P$33 (WAIT*)
WR_: IC3.27 (!WE), U$1.P$13 (WR*)
XTAL1: C9.2, Q1.1, U2.P40 (XTAL1)

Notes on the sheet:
3.579545mhz clock

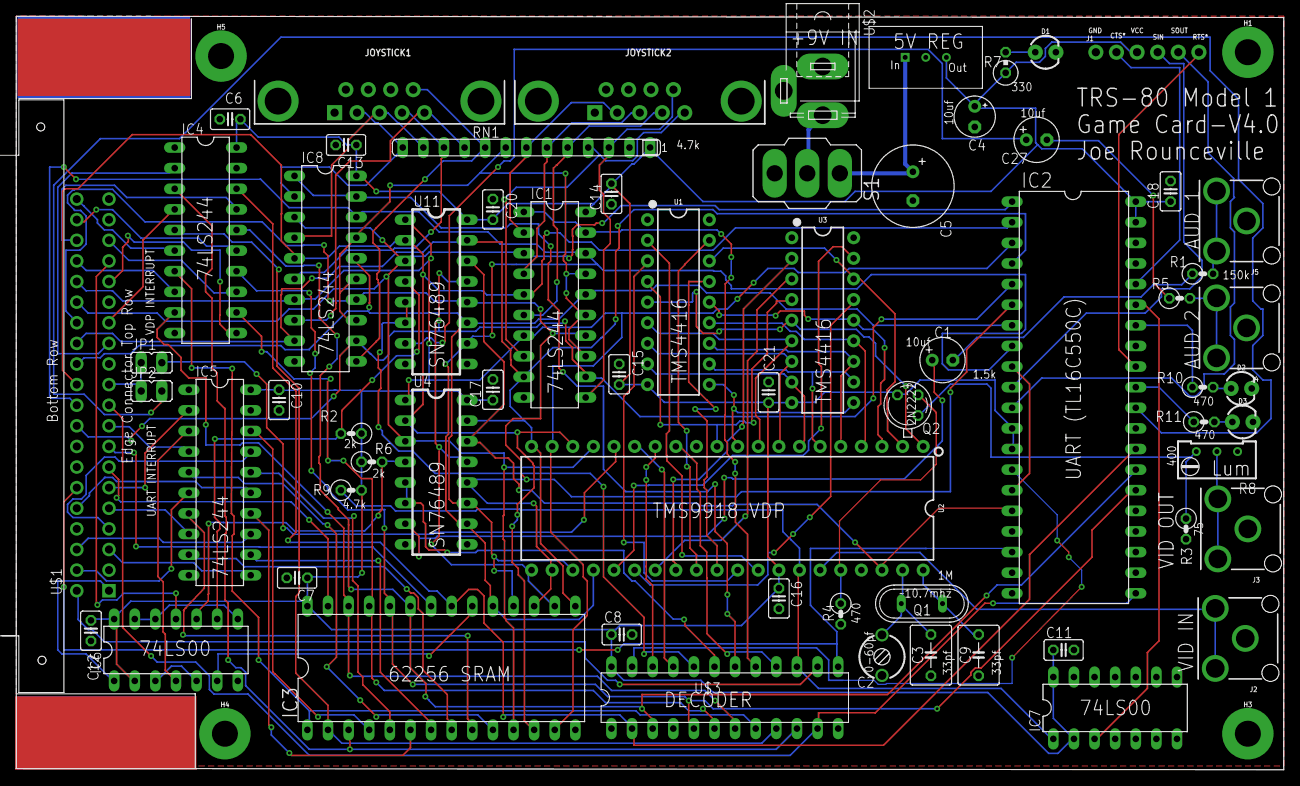
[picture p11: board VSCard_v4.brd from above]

Board: 2 copper layers, 156.2 x 92.9 mm, 69 parts (0 on the bottom side), 122 nets.

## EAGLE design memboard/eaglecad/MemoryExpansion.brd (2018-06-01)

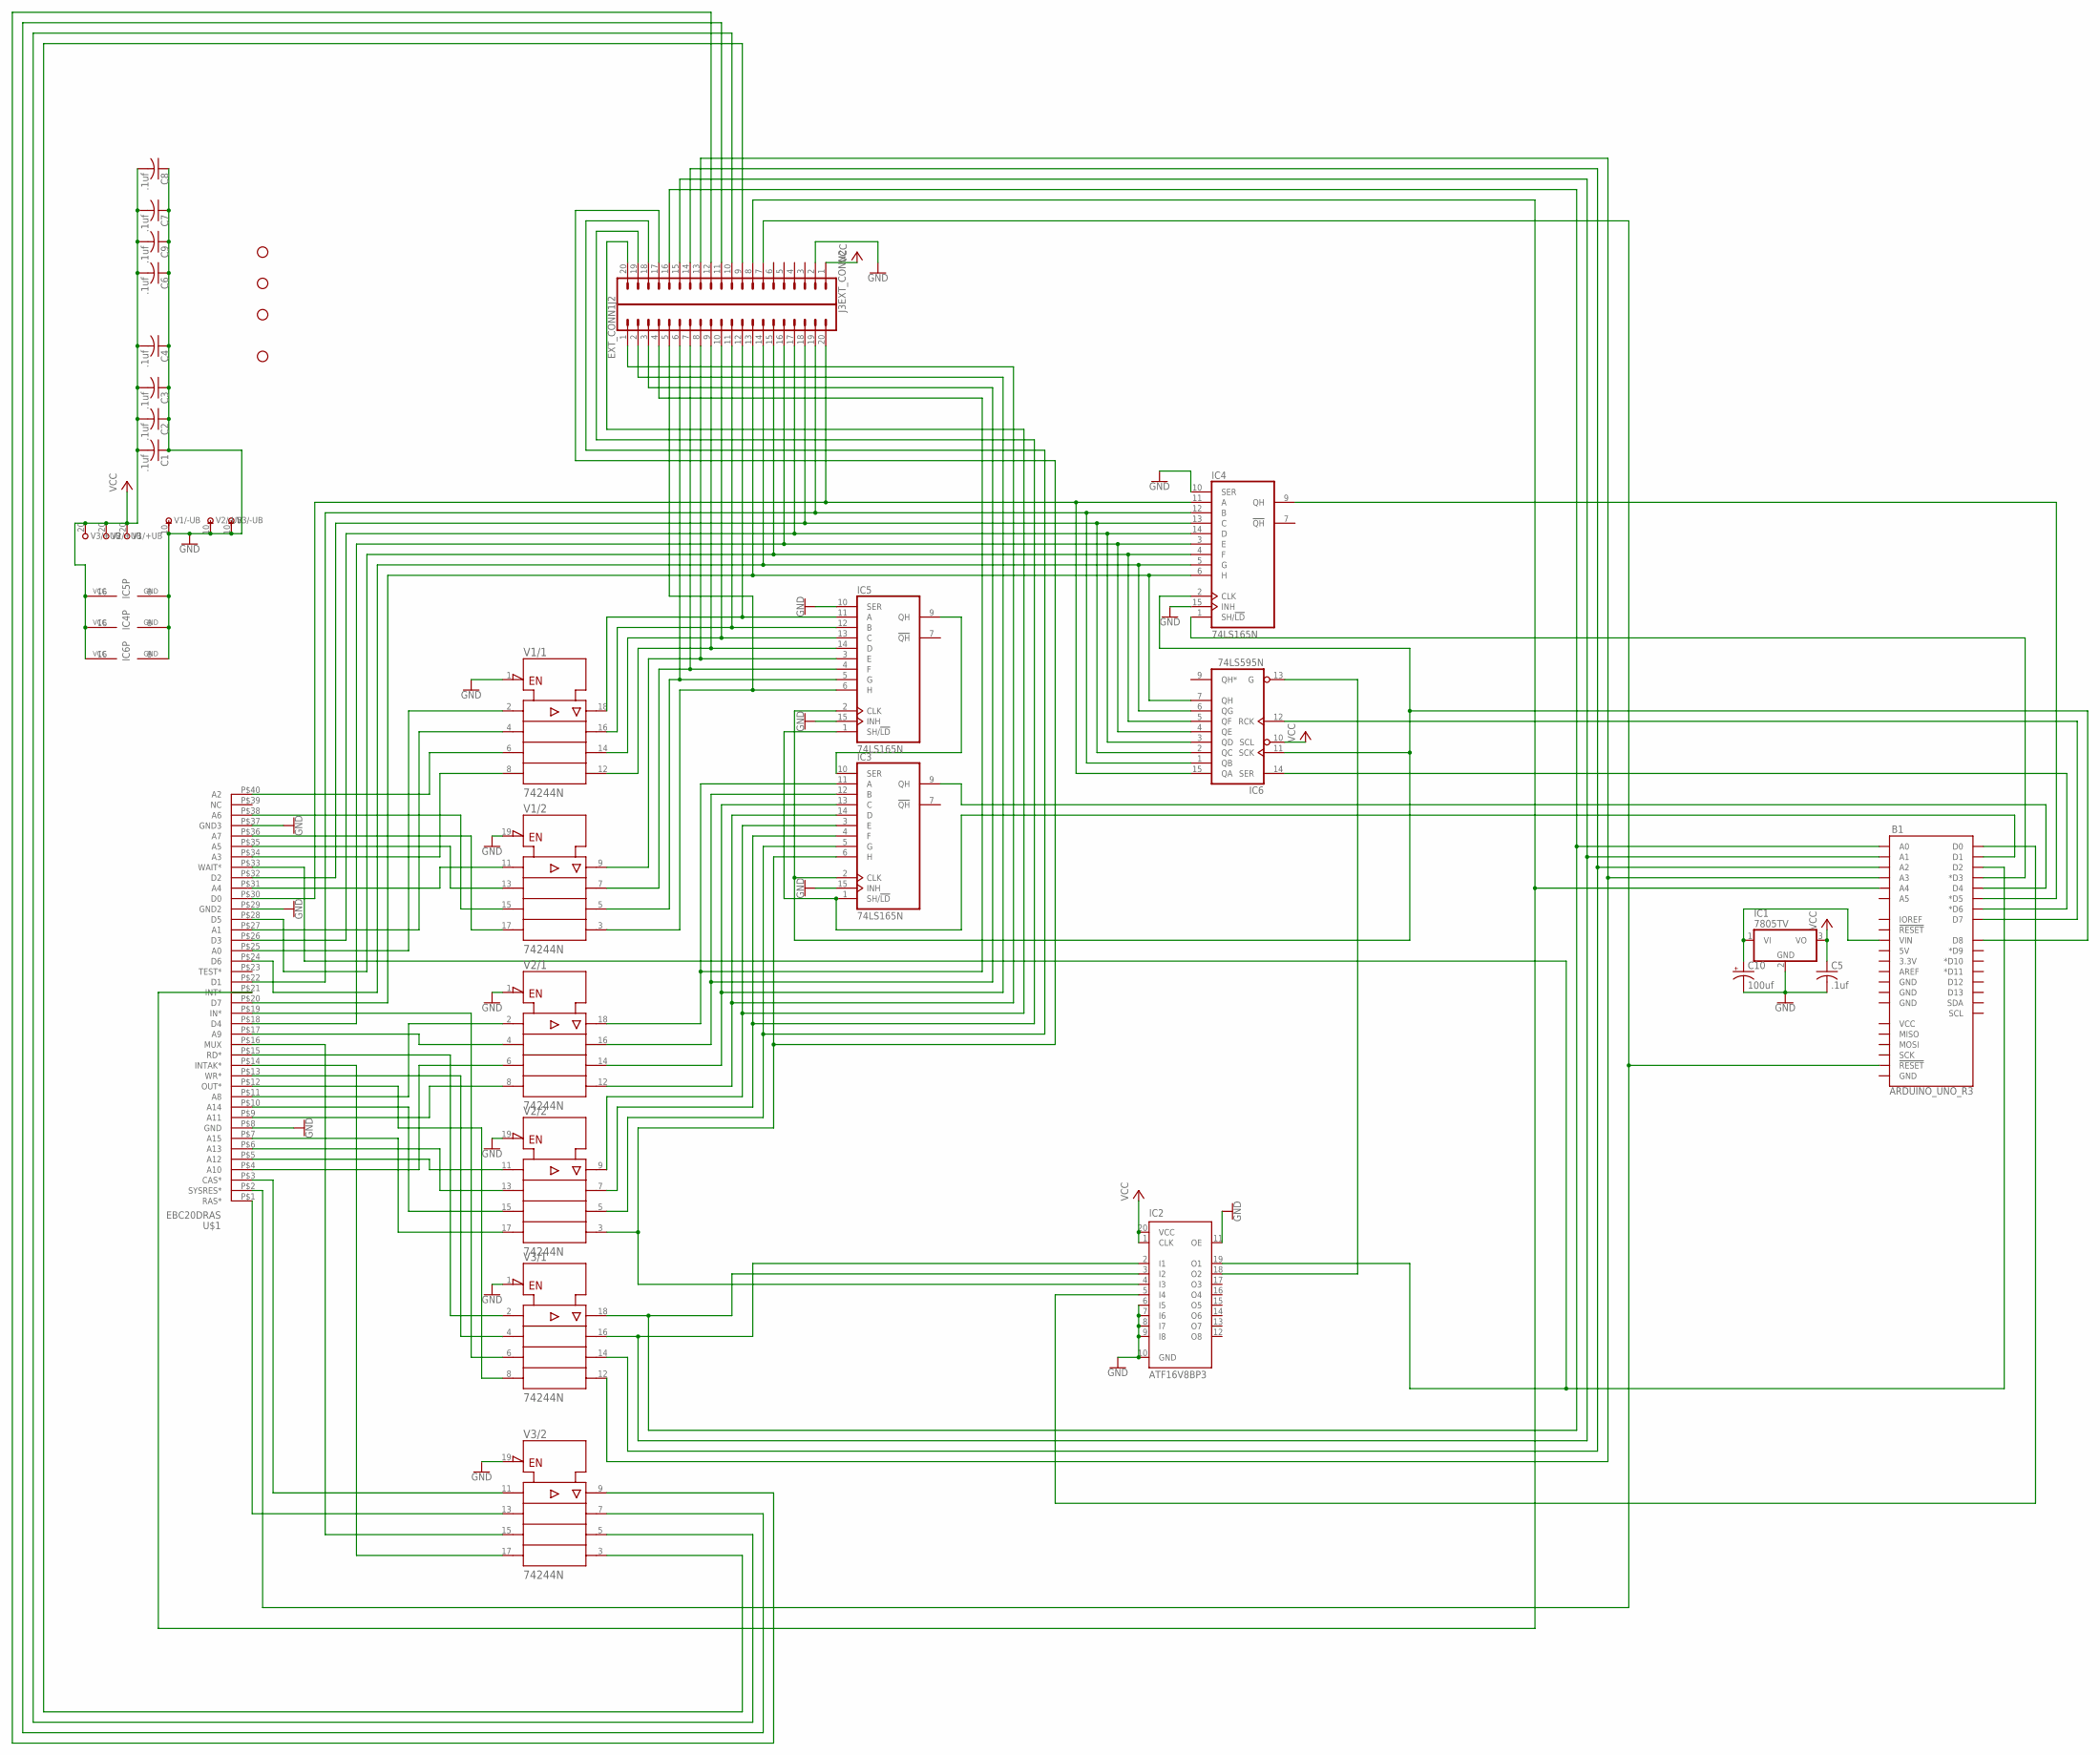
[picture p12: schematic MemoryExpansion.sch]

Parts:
B1: ARDUINO_UNO_R3; ARDUINO_R3
C1, C2, C3, C4, C5, C6, C7, C8, C9: .1uf; C025-024X044
C10: 100uf; E2-5
H1, H2, H3, H4: STAND-OFF
IC1: 7805TV; TO220V
IC2: ATF16V8BP3; DIL20
IC3, IC4, IC5: 74LS165N; DIL16
IC6: 74LS595N; DIL16
J2: EXT_CONN2; 1X20
J3: EXT_CONN1; 1X20
U$1: EBC20DRAS
V1, V2, V3: 74244N; DIL20

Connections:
A_12_NET: U$1.P$5 (A12), V2.11 (A1)
A_13_NET: U$1.P$6 (A13), V2.13 (A2)
A_14_NET: U$1.P$10 (A14), V2.15 (A3)
A_15_NET: U$1.P$7 (A15), V2.17 (A4)
BUF_A_12_NET: IC3.3 (E), J2.20, V2.9 (Y1)
BUF_A_13_NET: IC3.4 (F), J2.19, V2.7 (Y2)
BUF_A_14_NET: IC3.5 (G), J2.18, V2.5 (Y3)
BUF_A_15_NET: IC2.4 (I3), IC3.6 (H), J2.17, V2.3 (Y4)
BUF_IN_N_NET: B1.A2, J2.14, V3.14 (Y3)
BUF_OUT_N_NET: B1.A3, J2.13, V3.12 (Y4)
BUF_RD_N_NET: B1.A0, IC2.3 (I2), J2.16, V3.18 (Y1)
BUF_WR_N_NET: B1.A1, IC2.2 (I1), J2.15, V3.16 (Y2)
DECODE_ENABLE: B1.D0, IC2.5 (I4)
GND: C1.1, C2.1, C3.1, C4.1, C5.2, C6.1, C7.1, C8.1, C9.1, C10.-, IC1.2 (GND), IC2.6 (I5), IC2.7 (I6), IC2.8 (I7), IC2.9 (I8), IC2.10 (GND), IC2.11 (OE), IC3.8 (GND), IC3.15 (INH), IC4.8 (GND), IC4.10 (SER), IC4.15 (INH), IC5.8 (GND), IC5.10 (SER), IC5.15 (INH), IC6.8 (GND), J2.2, U$1.P$8 (GND), U$1.P$29 (GND2), U$1.P$37 (GND3), V1.1 (!G), V1.10 (-UB), V1.19 (!G), V2.1 (!G), V2.10 (-UB), V2.19 (!G), V3.1 (!G), V3.10 (-UB), V3.19 (!G)
IN_N_NET: U$1.P$19 (IN*), V3.6 (A3)
unnamed: U$1.P$25 (A0), V1.2 (A1)
unnamed: U$1.P$27 (A1), V1.4 (A2)
unnamed: U$1.P$40 (A2), V1.6 (A3)
unnamed: U$1.P$34 (A3), V1.8 (A4)
unnamed: U$1.P$31 (A4), V1.11 (A1)
unnamed: U$1.P$35 (A5), V1.13 (A2)
unnamed: U$1.P$38 (A6), V1.15 (A3)
unnamed: U$1.P$36 (A7), V1.17 (A4)
unnamed: U$1.P$11 (A8), V2.2 (A1)
unnamed: U$1.P$17 (A9), V2.4 (A2)
unnamed: U$1.P$4 (A10), V2.6 (A3)
unnamed: U$1.P$9 (A11), V2.8 (A4)
unnamed: B1.VIN, C10.+, IC1.1 (VI)
unnamed: B1.D6 (*D6), IC6.14 (SER)
unnamed: B1.D7, IC6.12 (RCK)
unnamed: U$1.P$3 (CAS*), V3.11 (A1)
unnamed: IC3.10 (SER), IC5.9 (QH)
unnamed: B1.D8, IC3.2 (CLK), IC4.2 (CLK), IC5.2 (CLK), IC6.11 (SCK)
unnamed: IC5.11 (A), J3.12, V1.18 (Y1)
unnamed: B1.D1, IC3.1 (SH/!LD), IC5.1 (SH/!LD)
unnamed: B1.D3 (*D3), IC4.1 (SH/!LD)
unnamed: B1.D4, IC3.9 (QH)
unnamed: B1.D5 (*D5), IC4.9 (QH)
unnamed: B1.A4, J2.8, U$1.P$21 (INT*)
unnamed: U$1.P$1 (RAS*), V3.13 (A2)
unnamed: U$1.P$16 (MUX), V3.15 (A3)
unnamed: IC5.12 (B), J3.11, V1.16 (Y2)
unnamed: IC5.13 (C), J3.10, V1.14 (Y3)
unnamed: IC5.14 (D), J3.9, V1.12 (Y4)
unnamed: IC5.3 (E), J3.8, V1.9 (Y1)
unnamed: IC5.4 (F), J3.7, V1.7 (Y2)
unnamed: IC5.5 (G), J3.6, V1.5 (Y3)
unnamed: IC5.6 (H), J3.5, V1.3 (Y4)
unnamed: U$1.P$14 (INTAK*), V3.17 (A4)
unnamed: IC3.11 (A), J3.4, V2.18 (Y1)
unnamed: IC3.12 (B), J3.3, V2.16 (Y2)
unnamed: IC3.13 (C), J3.2, V2.14 (Y3)
unnamed: IC3.14 (D), J3.1, V2.12 (Y4)
unnamed: B1.RESET@2 (!RESET!), J2.7, U$1.P$2 (SYSRES*)
unnamed: J2.12, V3.9 (Y1)
unnamed: J2.11, V3.7 (Y2)
unnamed: J2.10, V3.5 (Y3)
unnamed: IC4.11 (A), IC6.15 (QA), J3.20, U$1.P$30 (D0)
unnamed: IC4.12 (B), IC6.1 (QB), J3.19, U$1.P$22 (D1)
unnamed: IC4.13 (C), IC6.2 (QC), J3.18, U$1.P$32 (D2)
unnamed: IC4.14 (D), IC6.3 (QD), J3.17, U$1.P$26 (D3)
unnamed: IC4.3 (E), IC6.4 (QE), J3.16, U$1.P$18 (D4)
unnamed: IC4.4 (F), IC6.5 (QF), J3.15, U$1.P$28 (D5)
unnamed: IC4.5 (G), IC6.6 (QG), J3.14, U$1.P$24 (D6)
unnamed: IC4.6 (H), IC6.7 (QH), J3.13, U$1.P$20 (D7)
unnamed: J2.9, V3.3 (Y4)
OUT_N_NET: U$1.P$12 (OUT*), V3.8 (A4)
RDH_N: IC2.18 (O2), IC6.13 (G)
RD_N_NET: U$1.P$15 (RD*), V3.2 (A1)
VCC: C1.2, C2.2, C3.2, C4.2, C5.1, C6.2, C7.2, C8.2, C9.2, IC1.3 (VO), IC2.1 (CLK), IC2.20 (VCC), IC3.16 (VCC), IC4.16 (VCC), IC5.16 (VCC), IC6.10 (SCL), IC6.16 (VCC), J2.1, V1.20 (+UB), V2.20 (+UB), V3.20 (+UB)
WAIT/: B1.D2, IC2.19 (O1), U$1.P$33 (WAIT*)
WR_N_NET: U$1.P$13 (WR*), V3.4 (A2)

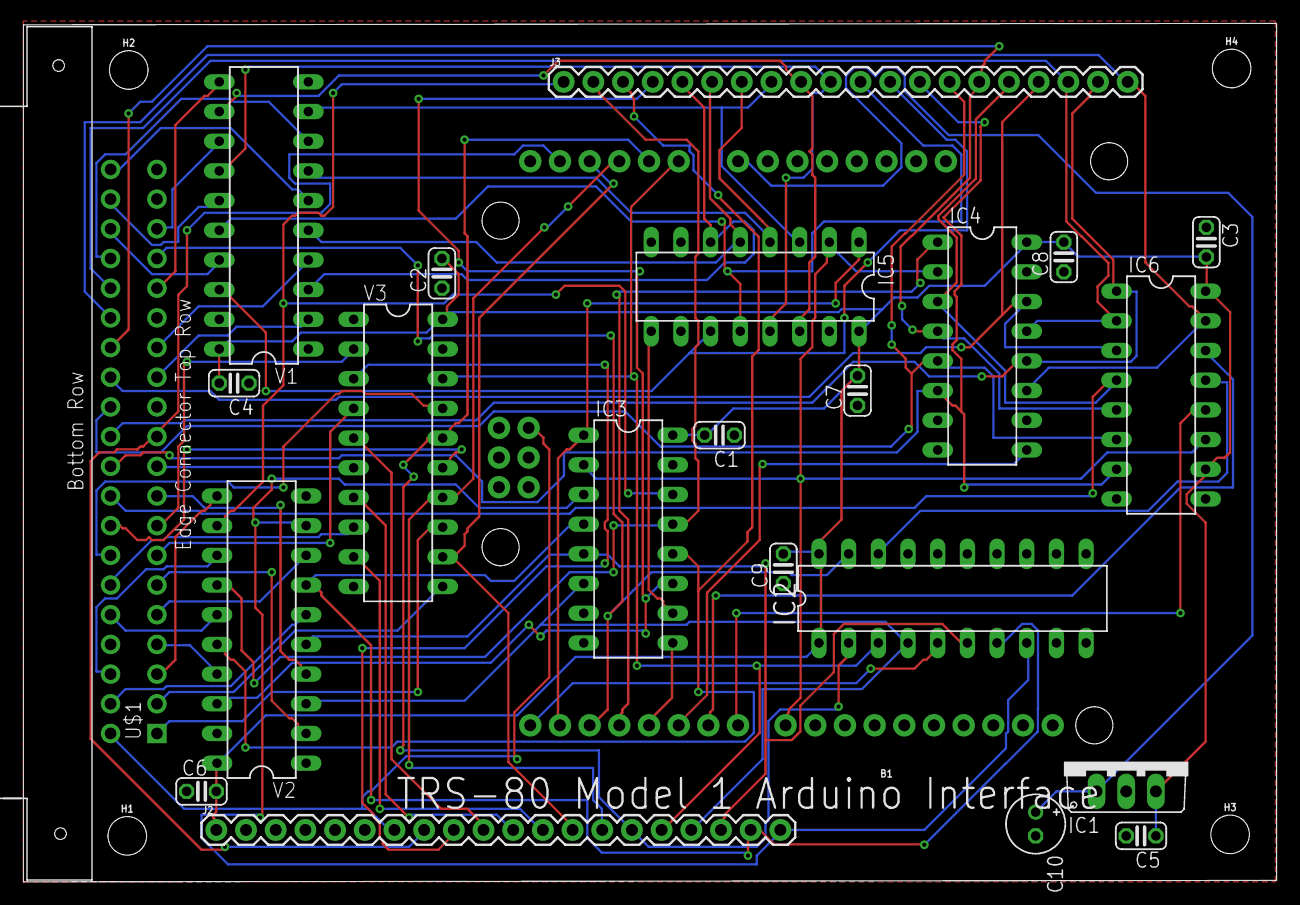
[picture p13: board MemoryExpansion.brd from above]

Board: 2 copper layers, 107.2 x 73.5 mm, 27 parts (0 on the bottom side), 72 nets.

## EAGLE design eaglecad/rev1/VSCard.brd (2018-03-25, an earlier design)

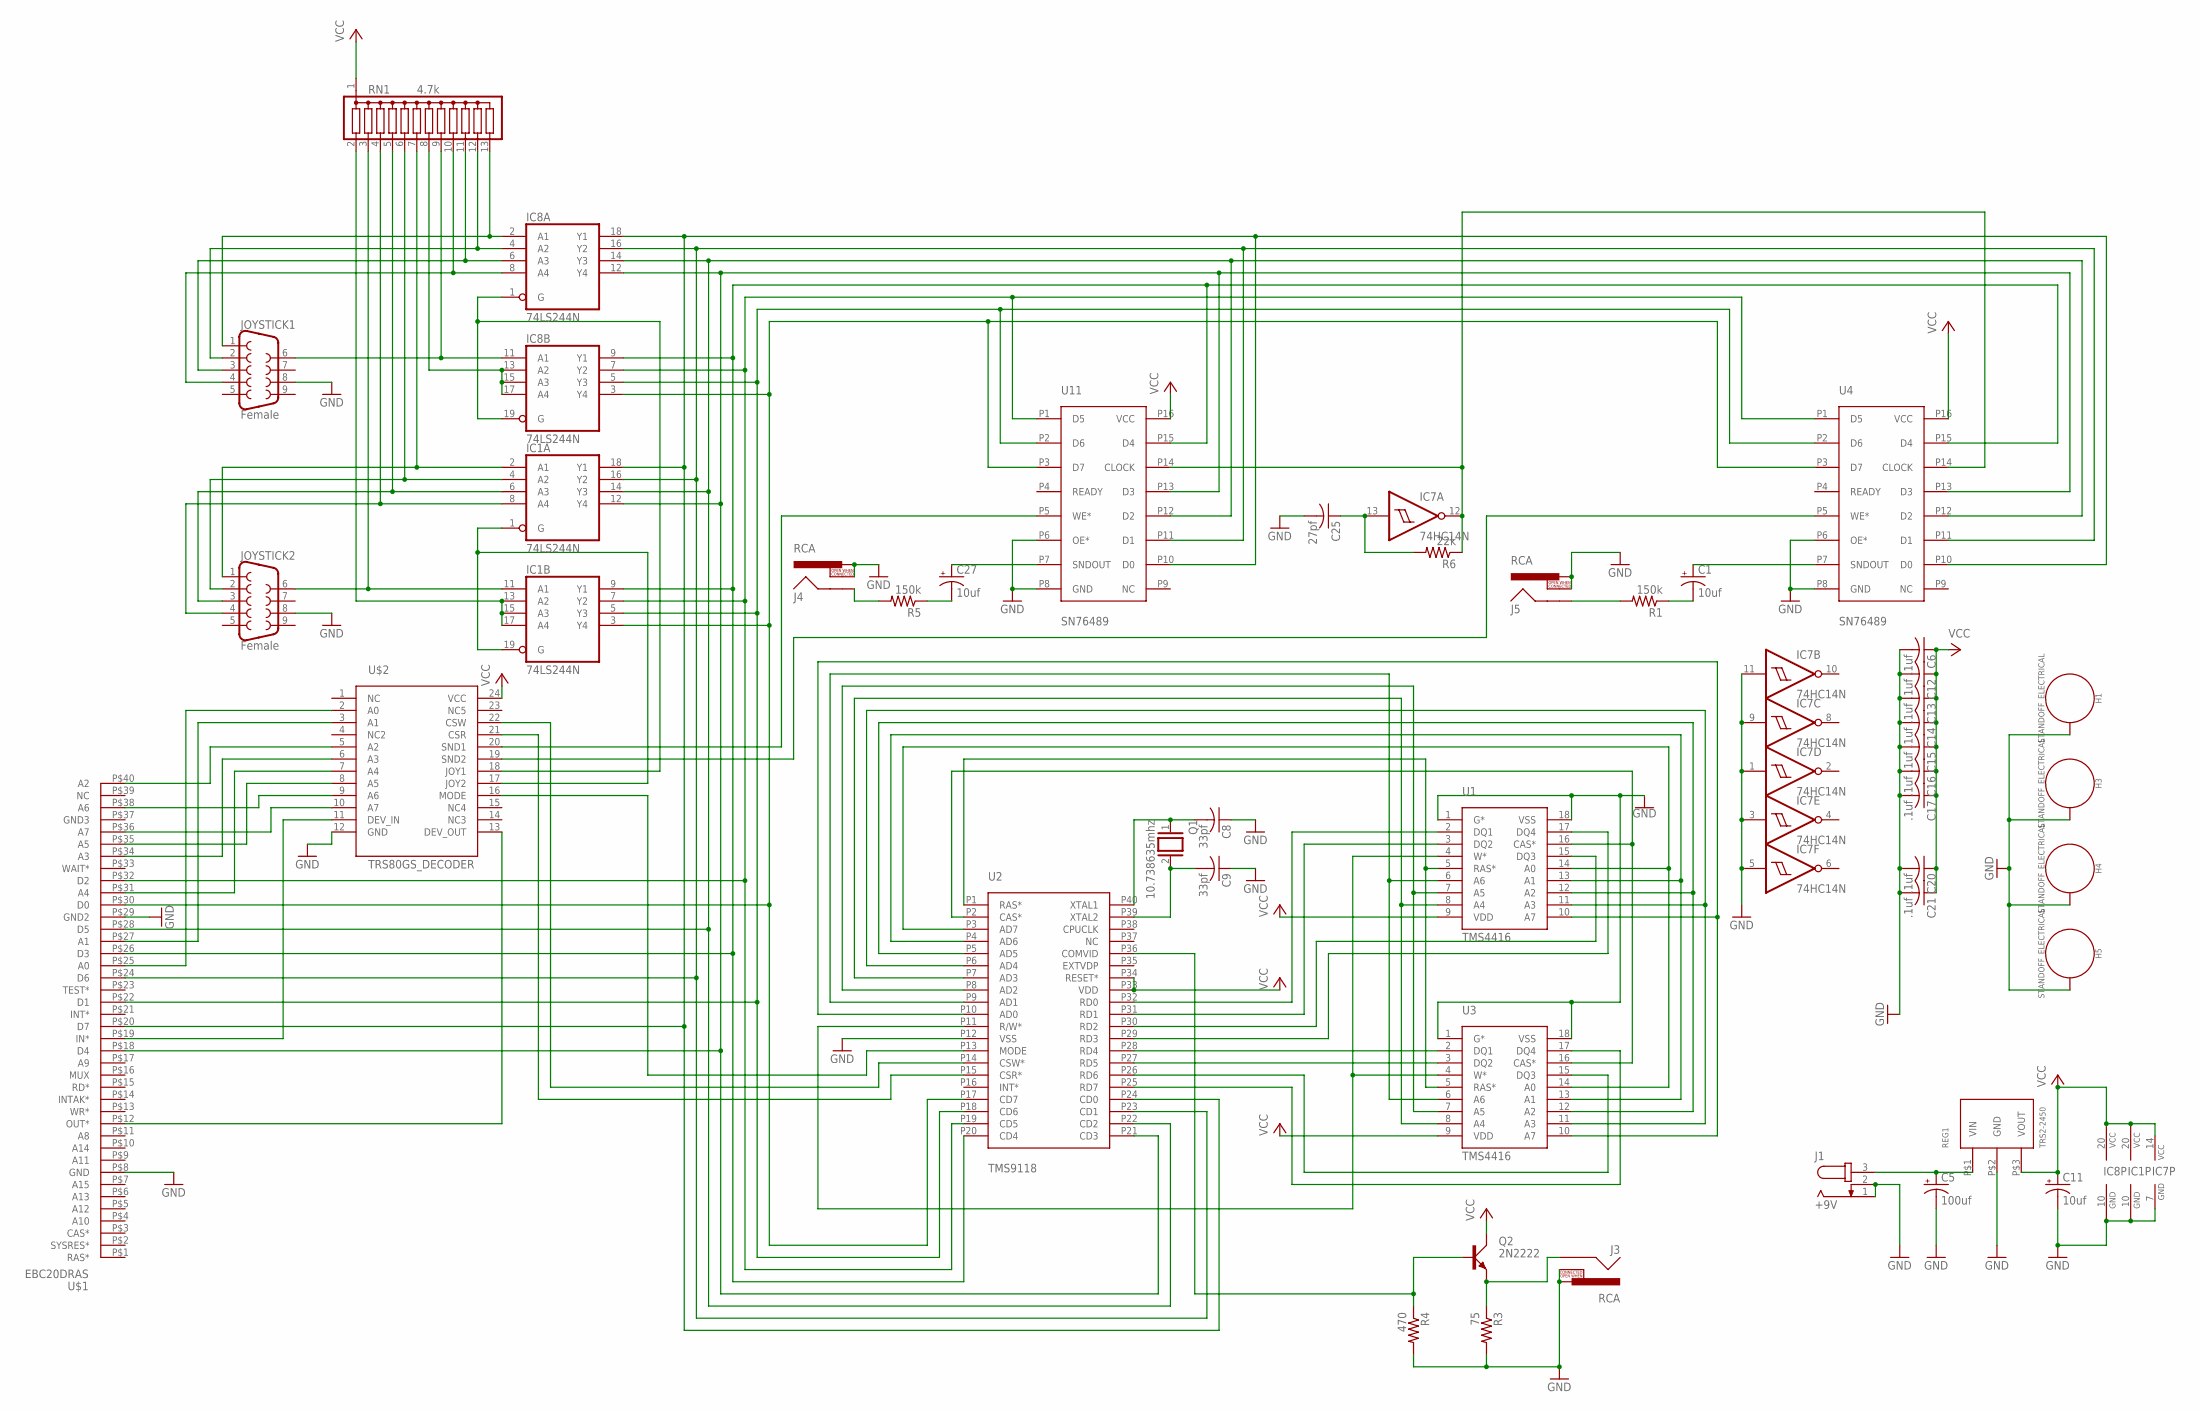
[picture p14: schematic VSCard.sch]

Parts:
C1, C27: 10uf; E2,5-6
C5: 100uf; E3,5-10
C6, C12, C13, C14, C15, C16, C17, C20, C21: .1uf; C025-025X050
C8, C9: 33pf; C050-050X075
C11: 10uf; E3,5-10
C25: 27pf; C025-025X050
H1, H3, H4, H5: STANDOFF_ELECTRICAL; STANDOFF-ELECTRICAL
IC1, IC8: 74LS244N; DIL20
IC7: 74HC14N; DIL14
J1: +9V; SPC4077
J3, J4, J5: RCA
JOYSTICK1, JOYSTICK2: Female; DB9
Q1: 10.738635mhz; QS
Q2: 2N2222; TO18A
R1, R5: 150k; 0207/2V
R3: 75; 0207/2V
R4: 470; 0207/2V
R6: 22k; 0207/2V
REG1: TRS2-2450; TRACON_REG
RN1: 4.7k; SIL13
U1, U3: TMS4416; DIP18
U2: TMS9118; DIP40_MCU
U4, U11: SN76489; DIP16
U$1: EBC20DRAS
U$2: TRS80GS_DECODER; DIP24SKI

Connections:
COMVID: Q2.B, R4.1, U2.P36 (COMVID)
COMVID-OUT: J3.SHELL, Q2.E, R3.1
D0: IC1.3 (Y4), IC8.3 (Y4), U2.P17 (CD7), U4.P3 (D7), U11.P3 (D7), U$1.P$30 (D0)
D1: IC1.5 (Y3), IC8.5 (Y3), U2.P18 (CD6), U4.P2 (D6), U11.P2 (D6), U$1.P$22 (D1)
D2: IC1.7 (Y2), IC8.7 (Y2), U2.P19 (CD5), U4.P1 (D5), U11.P1 (D5), U$1.P$32 (D2)
D3: IC1.9 (Y1), IC8.9 (Y1), U2.P20 (CD4), U4.P15 (D4), U11.P15 (D4), U$1.P$26 (D3)
D4: IC1.12 (Y4), IC8.12 (Y4), U2.P21 (CD3), U4.P13 (D3), U11.P13 (D3), U$1.P$18 (D4)
D5: IC1.14 (Y3), IC8.14 (Y3), U2.P22 (CD2), U4.P12 (D2), U11.P12 (D2), U$1.P$28 (D5)
D6: IC1.16 (Y2), IC8.16 (Y2), U2.P23 (CD1), U4.P11 (D1), U11.P11 (D1), U$1.P$24 (D6)
D7: IC1.18 (Y1), IC8.18 (Y1), U2.P24 (CD0), U4.P10 (D0), U11.P10 (D0), U$1.P$20 (D7)
DOWN: IC8.4 (A2), JOYSTICK1.2, RN1.12
DOWN1: IC1.4 (A2), JOYSTICK2.2, RN1.6
GND: C5.-, C6.2, C8.1, C9.1, C11.-, C12.2, C13.2, C14.2, C15.2, C16.2, C17.2, C20.2, C21.2, C25.2, H1.P1, H3.P1, H4.P1, H5.P1, IC1.10 (GND), IC7.1 (I), IC7.3 (I), IC7.5 (I), IC7.7 (GND), IC7.9 (I), IC7.11 (I), IC8.10 (GND), J1.1, J1.2, J3.PIN, J3.SWITCH, J4.PIN, J4.SWITCH, J5.PIN, J5.SWITCH, JOYSTICK1.8, JOYSTICK2.8, R3.2, R4.2, REG1.P$2 (GND), U1.1 (G*), U1.18 (VSS), U2.P12 (VSS), U3.1 (G*), U3.18 (VSS), U4.P6 (OE*), U4.P8 (GND), U11.P6 (OE*), U11.P8 (GND), U$1.P$8 (GND), U$1.P$29 (GND2), U$2.12 (GND)
JOY1_IN_ENABLE_N: IC8.1 (G), IC8.19 (G), U$2.18 (JOY1)
JOY1_IN_ENABLE_N1: IC1.1 (G), IC1.19 (G), U$2.17 (JOY2)
LEFT: IC8.6 (A3), JOYSTICK1.3, RN1.11
LEFT1: IC1.6 (A3), JOYSTICK2.3, RN1.5
unnamed: J4.SHELL, R5.2
unnamed: U$1.P$25 (A0), U$2.2 (A0)
unnamed: U$1.P$27 (A1), U$2.3 (A1)
unnamed: U$1.P$40 (A2), U$2.5 (A2)
unnamed: U$1.P$34 (A3), U$2.6 (A3)
unnamed: U$1.P$31 (A4), U$2.7 (A4)
unnamed: U$1.P$35 (A5), U$2.8 (A5)
unnamed: U$1.P$38 (A6), U$2.9 (A6)
unnamed: U$1.P$36 (A7), U$2.10 (A7)
unnamed: U$1.P$19 (IN*), U$2.11 (DEV_IN)
unnamed: IC1.13 (A2), IC1.15 (A3), IC1.17 (A4), RN1.2
unnamed: U$1.P$12 (OUT*), U$2.13 (DEV_OUT)
unnamed: U2.P13 (MODE), U$2.16 (MODE)
unnamed: U2.P14 (CSW*), U$2.22 (CSW)
unnamed: U2.P15 (CSR*), U$2.21 (CSR)
unnamed: U1.5 (RAS*), U2.P1 (RAS*), U3.5 (RAS*)
unnamed: U11.P5 (WE*), U$2.20 (SND1)
unnamed: U1.16 (CAS*), U2.P2 (CAS*), U3.16 (CAS*)
unnamed: U4.P5 (WE*), U$2.19 (SND2)
unnamed: C27.-, R5.1
unnamed: C25.1, IC7.13 (I), R6.2
unnamed: C1.-, R1.1
unnamed: J5.SHELL, R1.2
unnamed: IC8.13 (A2), IC8.15 (A3), IC8.17 (A4), RN1.8
RIGHT: IC8.8 (A4), JOYSTICK1.4, RN1.10
RIGHT1: IC1.8 (A4), JOYSTICK2.4, RN1.4
SN76489-CLOCK: IC7.12 (O), R6.1, U4.P14 (CLOCK), U11.P14 (CLOCK)
SNDOUT1: C27.+, U11.P7 (SNDOUT)
SNDOUT2: C1.+, U4.P7 (SNDOUT)
TMS9118_RW(*)_TMS4416_W(*): U1.4 (W*), U2.P11 (R/W*), U3.4 (W*)
TMS9918_AD0-TMS4416_A7: U1.10 (A7), U2.P10 (AD0), U3.10 (A7)
TMS9918_AD1-TMS4416_A6: U1.6 (A6), U2.P9 (AD1), U3.6 (A6)
TMS9918_AD2-TMS4416_A5: U1.7 (A5), U2.P8 (AD2), U3.7 (A5)
TMS9918_AD3-TMS4416_A4: U1.8 (A4), U2.P7 (AD3), U3.8 (A4)
TMS9918_AD4-TMS4416_A3: U1.11 (A3), U2.P6 (AD4), U3.11 (A3)
TMS9918_AD5-TMS4416_A2: U1.12 (A2), U2.P5 (AD5), U3.12 (A2)
TMS9918_AD6-TMS4416_A1: U1.13 (A1), U2.P4 (AD6), U3.13 (A1)
TMS9918_AD7-TMS4416_A0: U1.14 (A0), U2.P3 (AD7), U3.14 (A0)
TRIGGER: IC8.11 (A1), JOYSTICK1.6, RN1.9
TRIGGER1: IC1.11 (A1), JOYSTICK2.6, RN1.3
UP: IC8.2 (A1), JOYSTICK1.1, RN1.13
UP1: IC1.2 (A1), JOYSTICK2.1, RN1.7
VCC: C6.1, C11.+, C12.1, C13.1, C14.1, C15.1, C16.1, C17.1, C20.1, C21.1, IC1.20 (VCC), IC7.14 (VCC), IC8.20 (VCC), Q2.C, REG1.P$3 (VOUT), RN1.1, U1.9 (VDD), U2.P33 (VDD), U2.P34 (RESET*), U3.9 (VDD), U4.P16 (VCC), U11.P16 (VCC), U$2.24 (VCC)
VDP-RD0: U1.2 (DQ1), U2.P32 (RD0)
VDP-RD1: U1.3 (DQ2), U2.P31 (RD1)
VDP-RD2: U1.15 (DQ3), U2.P30 (RD2)
VDP-RD3: U1.17 (DQ4), U2.P29 (RD3)
VDP-RD4: U2.P28 (RD4), U3.2 (DQ1)
VDP-RD5: U2.P27 (RD5), U3.3 (DQ2)
VDP-RD6: U2.P26 (RD6), U3.15 (DQ3)
VDP-RD7: U2.P25 (RD7), U3.17 (DQ4)
VOLTAGE-IN: C5.+, J1.3, REG1.P$1 (VIN)
XTAL1: C8.2, Q1.1, U2.P40 (XTAL1)
XTAL2: C9.2, Q1.2, U2.P39 (XTAL2)

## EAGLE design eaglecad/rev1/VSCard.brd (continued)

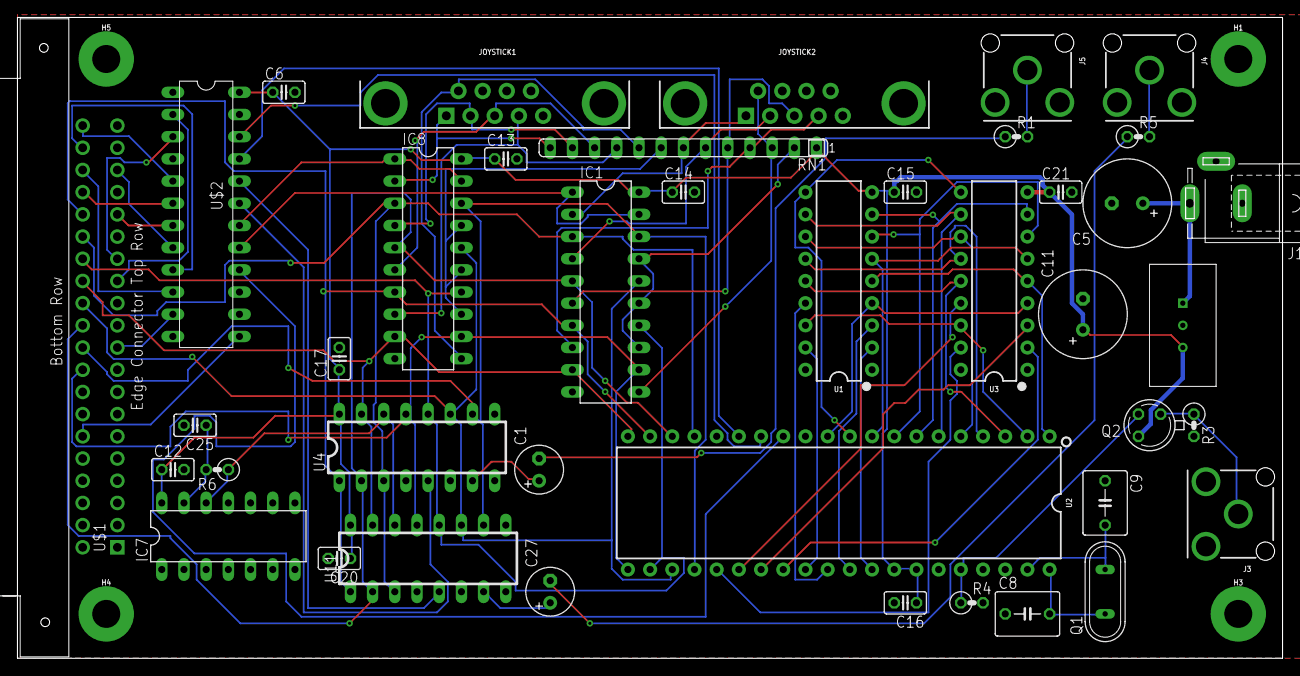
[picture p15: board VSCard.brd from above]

Board: 2 copper layers, 144.8 x 73.3 mm, 45 parts (0 on the bottom side), 71 nets.

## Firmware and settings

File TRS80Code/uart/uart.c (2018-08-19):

#include <stdio.h>
#include <stdlib.h>


#define DEBUG 1
#undef DEBUG


#define WHITESPACE 64
#define EQUALS     65
#define INVALID    66


unsigned char control_reg;
unsigned char byt;
unsigned char workBuff[400];
#define OUTLEN 300
unsigned char decodedData[OUTLEN];
unsigned int szDecodedData;
unsigned int timeout;


__sfr __at 0xe0 UART_RECEIVE_HOLDING_REGISTER;
__sfr __at 0xe0 UART_TRANSMIT_HOLDING_REGISTER;
__sfr __at 0xe0 UART_DIVISOR_LSB;
__sfr __at 0xe1 UART_DIVISOR_MSB;
__sfr __at 0xe1 UART_INTERRUPT_ENABLE_REGISTER;
//__sfr __at 0xe2 UART_INTERRUPT_STATUS_REGISTER;
__sfr __at 0xe2 UART_FIFO_CONTROL_REGISTER;
__sfr __at 0xe3 UART_LINE_CONTROL_REGISTER;
__sfr __at 0xe4 UART_MODEM_CONTROL_REGISTER;
__sfr __at 0xe5 UART_LINE_STATUS_REGISTER;
//__sfr __at 0xe6 UART_MODEM_STATUS_REGISTER;
//__sfr __at 0xe7 UART_SCRATCH_PAD_REGISTER;
__sfr __at 0x82 PORTX82;
__sfr __at 0x83 PORTX83;



void audioSilence() {
  PORTX82 = 255;
  PORTX82 = 253;
  PORTX82 = 251;
  PORTX82 = 249;
  PORTX83 = 255;
  PORTX83 = 253;
  PORTX83 = 251;
  PORTX83 = 249;
}

/*
void hold(unsigned int x) {
    for(unsigned int y = 0; y<x;y++) {
      #pragma asm
      nop
      #pragma endasm
    }
}
*/

void init_uart() {
  // disable interrupts
  UART_INTERRUPT_ENABLE_REGISTER = 0x00;
  
  // mask to set DLAB on
  UART_LINE_CONTROL_REGISTER = 0x80;

  /*
      Baud    Divisor
      1200    186
      1800    124
      2000    113
      2400     93
      3600     62
      4800     47
      7200     31
      9600     23
     19200     12
     38400      6
     57600      4
    115200      2
  */
  UART_DIVISOR_LSB = 4;

  // set MSB of the divisor
  UART_DIVISOR_MSB = 0;

  // 8 bit, 1 stop bit, no parity, and clear DLAB
  UART_LINE_CONTROL_REGISTER = 0x03;

  // turn on FIFO, 14 char depth, clear FIFO buffers
  UART_FIFO_CONTROL_REGISTER = 0xc7;

  // turn on auto flow control
  UART_MODEM_CONTROL_REGISTER = 0x22;
}


static const unsigned char d[] = {
    66,66,66,66,66,66,66,66,66,66,64,66,66,66,66,66,66,66,66,66,66,66,66,66,66,
    66,66,66,66,66,66,66,66,66,66,66,66,66,66,66,66,66,66,62,66,66,66,63,52,53,
    54,55,56,57,58,59,60,61,66,66,66,65,66,66,66, 0, 1, 2, 3, 4, 5, 6, 7, 8, 9,
    10,11,12,13,14,15,16,17,18,19,20,21,22,23,24,25,66,66,66,66,66,66,26,27,28,
    29,30,31,32,33,34,35,36,37,38,39,40,41,42,43,44,45,46,47,48,49,50,51,66,66,
    66,66,66,66,66,66,66,66,66,66,66,66,66,66,66,66,66,66,66,66,66,66,66,66,66,
    66,66,66,66,66,66,66,66,66,66,66,66,66,66,66,66,66,66,66,66,66,66,66,66,66,
    66,66,66,66,66,66,66,66,66,66,66,66,66,66,66,66,66,66,66,66,66,66,66,66,66,
    66,66,66,66,66,66,66,66,66,66,66,66,66,66,66,66,66,66,66,66,66,66,66,66,66,
    66,66,66,66,66,66,66,66,66,66,66,66,66,66,66,66,66,66,66,66,66,66,66,66,66,
    66,66,66,66,66,66
};

int base64decode (char *in, size_t inLen, unsigned char *out) { 
    char *end = in + inLen;
    char iter = 0;
    uint32_t buf = 0;
    size_t len = 0;
    //printf("  BASE64DECODE(*,%u,*) ",inLen);
    
    while (in < end) {
        unsigned char c = d[*in++];
        //printf(" %u",(unsigned char)c);
        switch (c) {
        case WHITESPACE: continue;   /* skip whitespace */
        case INVALID:    return 1;   /* invalid input, return error */
        case EQUALS:                 /* pad character, end of data */
            in = end;
            continue;
        default:
            buf = buf << 6 | c;
            iter++; // increment the number of iteration
            /* If the buffer is full, split it into bytes */
            if (iter == 4) {
                len+=3;
                *(out++) = (buf >> 16) & 255;
                *(out++) = (buf >> 8) & 255;
                *(out++) = buf & 255;
                buf = 0; iter = 0;

            }   
        }
    }
    if (iter == 3) {
        if ((len += 2) > OUTLEN) return 1;
        *(out++) = (buf >> 10) & 255;
        *(out++) = (buf >> 2) & 255;
    }
    else if (iter == 2) {
        if (++len > OUTLEN) return 1;
        *(out++) = (buf >> 4) & 255;
    }

    //printf(" (ITER=%d,LEN=%d)\n",iter,len);

    szDecodedData = len;
    return 0;
}

void sendByte(char x) {
    byt = 0x20;

    do {
        #pragma asm
        nop
        #pragma endasm
        //printf("%d ", UART_LINE_STATUS_REGISTER);
    }
    while((UART_LINE_STATUS_REGISTER & byt) == 0);
    
    UART_TRANSMIT_HOLDING_REGISTER = x;
}

unsigned char getByte() {
    byt = 0x01;
    timeout = 65534;

    do {
      timeout--;
    }
    while((UART_LINE_STATUS_REGISTER & byt) == 0 && timeout > 0);

    return UART_RECEIVE_HOLDING_REGISTER;
}


void sendString(char* s) {
  static int i;
  static int j;

  //printf("IN SENDSTRING: %s\n", s);
  j = strlen(s);

  for(i=0;i<j;i++) {
    sendByte(*(s+i));
  }
  sendByte(13);
}

char* getString() {
  static int i;
  static char c;

  i = 0;
  c = 0;
  timeout = 65534;

  while(c != 13) {
    c = getByte();
    if(timeout == 0)
      return NULL;

    if(c != 13 && c != 10) {
      workBuff[i] = c;
      workBuff[i+1] = 0x0;
      i++;
    }
  }

  return workBuff;
}

void printLSResponse() {
   static unsigned char c;
   static long chksum;

   printf("\n  ");

   chksum = 0;
   do {
     c = getByte();
     chksum += c;
     
     if(c == ':') {
         printf("\n  ");
     }
     else
         putchar(c);
    }
    while(c != 13); 
    printf("\nCHKSUM: %ld\n", chksum); 
}


void drawChar(unsigned long offset, unsigned long count, unsigned char cc) {
  static unsigned long of;
  static unsigned long cnt;
  static unsigned char ccs;
  of = offset;
  cnt = count;
  ccs = cc;
  
  #pragma asm
        push   HL
        push   DE
        push   BC
        push   AF
        ld     HL,(_st_drawChar_of)       
        ld     DE,(_st_drawChar_of)
        INC    DE      
        ld     BC,(_st_drawChar_cnt)
        ld     a,(_st_drawChar_ccs)
        ld     (HL),a
        ldir 
        pop    AF
        pop    BC
        pop    DE
        pop    HL        
  #pragma endasm 
}

void cls() {
  drawChar((unsigned long)0x3c00, (unsigned long)0x3ff, (unsigned char)128);
}

void drawProgress(unsigned int xBytes) {
  drawChar((unsigned long)0x3f80, (unsigned long)64, (unsigned char)128);

  if(xBytes > 0) {
    drawChar((unsigned long)0x3f80, (unsigned long)xBytes, (unsigned char)153);
  }
}

int startsWith (char* base, char* str) {
    return (strstr(base, str) - base) == 0;
}


void handleLoadCmd(char* s) {
 static unsigned int addrToJump;

  unsigned int chk;
  unsigned int bytePerc;
  unsigned int address;
  unsigned int bytePercentage;
  unsigned long calcChk;
  char c[5];
  unsigned char temp;
  unsigned char blkCtr;

  c[4] = 0x0;

  //printf("in HANDLELOADCMD: %s",s);
  

  blkCtr = 0;

  sendString(s);  // send the LOADCMD to server
  if(getString() == NULL) {    // get server's response
    printf("\nTIMEOUT.");
    return;
  }

  if(startsWith(workBuff,"ERROR") == 1) {
      puts(workBuff);
      return;
  }

  while(strncmp(workBuff,"GET_DONE",strlen(workBuff)) != 0) {
    //printf("%s\n", workBuff);
    blkCtr++;
    if(startsWith(workBuff,"OBJ ") == 1) {
      //printf("  %s\n",workBuff);
      //printf("  MOVNG PAST OBJ\n");
      memmove(workBuff, workBuff+4, strlen(workBuff));
      c[0] = *(workBuff);
      c[1] = *(workBuff+1);
      c[2] = *(workBuff+2);
      c[3] = *(workBuff+3);
      //printf("  GETTING ADDRESS\n");
      address = strtoul(c, NULL, 16);
      //printf("  ADDR = %X\n", address);
      //printf("  MOVING PAST ADDR\n");
      memmove(workBuff, workBuff+5, strlen(workBuff));

      c[0] = *(workBuff);
      c[1] = *(workBuff+1);
      c[2] = *(workBuff+2);
      c[3] = *(workBuff+3);
      bytePercentage = strtoul(c, NULL, 16);
      memmove(workBuff, workBuff+5, strlen(workBuff));


      c[0] = *(workBuff);
      c[1] = *(workBuff+1);
      c[2] = *(workBuff+2);
      c[3] = *(workBuff+3);
      //printf("  GETTING CHECKSM\n");
      chk = strtoul(c, NULL, 16);
      //printf("  CHKSUM = %d\n", chk);
      //printf("  MOVING PAST CHECKSM\n");
      memmove(workBuff, workBuff+5, strlen(workBuff));
      //printf("  INVOKING BASE64DECODE\n");

      if(base64decode(workBuff, strlen(workBuff), &decodedData) != 0) {
        printf("Problem with base64decode!\n");
      }
      //printf("  DECODED DATA SIZE %d\n", szDecodedData);
      calcChk = 0;
      for(int i=0;i<szDecodedData;i++) {
        temp = *(decodedData+i);
        calcChk = calcChk + (unsigned long)temp;
        //if(szDecodedData < 50)
          //printf("(%d) %ld ",temp, calcChk);
      }

      //printf("\n  CALCULATED CHECKSM %d\n", calcChk);

      if(calcChk == chk) {
        drawProgress(bytePercentage);
        memcpy(address, decodedData,szDecodedData);
        sendString("OK");
        if(getString() == NULL) {
          printf("\nTIMEOUT.");
          return;
        }
      }
      else {
        printf("  CHK MISMATCH: %d != %d\n",chk, calcChk);
        sendString("RESEND");
        if(getString() == NULL) {
          printf("\nTIMEOUT.");
          return;
        }
      }
    } 
    else if(startsWith(workBuff,"ENTPT ") == 1) {
      memmove(workBuff, workBuff+6, strlen(workBuff));
      c[0] = *(workBuff);
      c[1] = *(workBuff+1);
      c[2] = *(workBuff+2);
      c[3] = *(workBuff+3);
      address = strtoul(c, NULL, 16);
      sendString("OK");
      if(getString() == NULL) {
          printf("\nTIMEOUT.");
          return;
      }

      printf("\nPROGRAM ENTRY POINT: %ud\n", address);
      printf("ENTER 'G' TO RUN AT ENTRY POINT, OR 'C' TO CANCEL\n");
      fgets(workBuff,255,stdin);
      if(startsWith(workBuff,"G") == 1) {
          addrToJump = address;  // sets HL
          #pragma asm
            jp    (hl)
          #pragma endasm
      }
      else {
        break;
      }
    }
    else {
      printf("UNKNOWN MSG FROM SERVER, %s\n", workBuff);
        sendString("OK");
        if(getString() == NULL) {
          printf("\nTIMEOUT.");
          return;
        }
    }
  }

    printf("\n");
    #ifdef DEBUG
      puts("  EXIT-HANDLELOADCMD(),");
    #endif
}

void sendCommandAndDumpResult(char* s) {
    #ifdef DEBUG
      puts("  ENTER-SENDCOMMANDANDDUMPRESULT(),");
    #endif
    sendString(s);
    printLSResponse(); 
    #ifdef DEBUG     
      puts("  EXIT-SENDCOMMANDANDDUMPRESULT(),");
    #endif
}

int main()
{
  char buf[128];
  int szBuf;

  cls();
  audioSilence();
  puts("          TRS-80 MODEL 1 UART OS VYYYY-MM-DD-HH-MM-SS");
  for(szBuf=0;szBuf<63;szBuf++)
    fputc(131,stdout);

  init_uart();

  fputs("\nCOMMAND?",stdout);
  while(strncmp(buf,"X",strlen(buf)) != 0) {
    fputs("\n>",stdout);
    fgets(buf,128,stdin);
    szBuf = strlen(buf);
    if (szBuf > 0 && buf[szBuf - 1] == '\n')
            buf[szBuf - 1] = '\0';

    if(strncmp(buf,"X",szBuf) == 0 || strncmp(buf,"Q",szBuf) == 0) {
      break;
    }
    else if (startsWith(buf,"GET") == 1) {
      handleLoadCmd(buf);
    }
    else if(startsWith(buf,"LS") == 1) {
      sendCommandAndDumpResult(buf);
    }
    else if(startsWith(buf,"SETDELAY") == 1) {
      sendCommandAndDumpResult(buf);
    }
    else {
      printf("UNKNOWN CMD: %s\n",buf);
    }
  }

  printf("DONE. PRESS ENTER.\n");
  fgets(buf,128,stdin);

  #pragma asm
    jp    0
  #pragma endasm

  exit(-1);
}

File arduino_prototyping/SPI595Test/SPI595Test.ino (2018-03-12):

// This code runs on Arduino UNO R3

// *****************************************************************************************
// * TMS9118A test code
// *  
// * This code sets up a TMS9118A VDP chip and has it toggle through its background colors 
// * It uses two 8 bit shift registers (74HC595) to represent a data bus (lower 8 bits)
// * and the upper 3 bits of the other shift register represent MODE, CSR*, and CSW*
// * The VDP's RESET* is also tied to the lower bit (A5) of the Arduino through a switching 
// * transistor
// *****************************************************************************************


#include <SPI.h>

const int latchPin = A0;
const int clockPin = 13;
const int dataPin  = 11;
volatile unsigned int j;

void setup() {
  DDRC = B00111111;             // turn all the pins on PORTC (the analog pins) on

  pinMode(latchPin, OUTPUT);    // set latch as output mode
  pinMode(clockPin, OUTPUT);    // set clock as output mode
  pinMode(dataPin, OUTPUT);     // set data as output mode
  digitalWrite(latchPin, HIGH); // turn on the latch
  digitalWrite(clockPin, LOW);  // turn off the clock
  digitalWrite(dataPin, LOW);   // turn off any data


  // set up hardware SPI
  SPI.setBitOrder(MSBFIRST);
  SPI.setDataMode(SPI_MODE0);
  SPI.setClockDivider(SPI_CLOCK_DIV2);
  SPI.begin();

  PORTC = B00000000;           // invoke reset circuit
  delay(200);                  // wait for the reset
  PORTC = B00000001;           // toggle reset pin back up
  delay(200);

  // register 0
  writeRegister(0, B00000000);  // graphics mode 1, no external video

  // register 1
  writeRegister(1, B11000000); // 16k, Enable display, Disable interrupts, 8x8 sprites, magnification off

  // register 2
  writeRegister(2, B00000101); // address of name table in VRAM = 0x1400

  // register 3
  writeRegister(3, B10000000); // address of color table in VRAM = 0x2000

  // register 4  
  writeRegister(4, B00000001); // address of pattern table in VRAM = 0x0800

  // register 5 
  writeRegister(5, B00100000); // address of sprite attribute table in VRAM = 0x1000

  // register 6
  writeRegister(6, B00000000); // address of sprite pattern table in VRAM = 0x0000

  // register 7
  writeRegister(7, B00000011);// set background color
}

inline void writeRegister(byte reg, byte data) {
  writeData(data);
  writeData(reg | 128);
}

inline void writeData(unsigned int u) {
  u = u & 0b0001111111111111;
  j = u | 0b1010000000000000;
  // MODE high, CSW* LOW, CSR* HIGH, DATA=j

  PORTC = B00000001;   // set latch low (leaving reset high)
  SPI.transfer16(j);
  PORTC = B00111111;   // set latch high

  // MODE high, CSW* HIGH, CSR* HIGH, DATA=j
  j = u | 0b1110000000000000;

  PORTC = B00000001;   // set latch low (leaving reset high)
  SPI.transfer16(j);
  PORTC = B00111111;   // set latch high

  // MODE high, CSW* LOW, CSR* HIGH, DATA=j
  j = u | 0b1010000000000000;

  PORTC = B00000001;    // set latch low (leaving reset high)
  SPI.transfer16(j);
  PORTC = B00111111;    // set latch high
}

void loop() {
  for (int i = 1; i < 16; i++) {
    writeRegister(7,i);
    delay(1000);
  }
}

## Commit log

2018-03-12 minor fix to reset code
    [SPI595Test.ino]
2018-03-12 code cleanup in arduino test stuff
2018-03-25 new version with PLD glue logic chip
    [VSCard.brd, VSCard.sch]
2018-06-01 v2 graphics/sound design and memboard initial design
    [MemoryExpansion.brd, MemoryExpansion.sch, VSCard_v2.brd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]
2018-06-01 added picture of prototype card
2018-06-15 schematic updates
    [VSCard_v2.brd, VSCard_v2.sch]
2018-06-16 board with SRAM
    [VSCard_v3.brd, VSCard_v3.sch]
2018-06-28 added revised card that includes improved clock circuit
    [VSCard_v3.1.brd, VSCard_v3.1.sch]
2018-07-14 version 4 of the board -- adds UART
    [VSCard_v4.brd, VSCard_v4.sch]
2018-07-24 got rid of extra crystal for UART -- used VDP CPUCLK output instead
    [VSCard_v4.brd, VSCard_v4.sch]
2018-07-25 initial UART tests
2018-07-26 updated uart code
2018-07-27 minor uart fixes
2018-07-29 updated uart code -- first working version
2018-07-30 more uart coding
2018-07-31 uart code fixes
2018-08-19 updated uart handler code
2018-11-04 uart stuff - cmd files that can be uploaded

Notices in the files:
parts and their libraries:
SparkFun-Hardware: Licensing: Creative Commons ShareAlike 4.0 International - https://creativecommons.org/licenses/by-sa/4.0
